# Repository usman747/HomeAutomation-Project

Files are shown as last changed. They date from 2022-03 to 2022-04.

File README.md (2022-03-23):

# SmartHomeAutomation-Project
• Alarm clock was synced with room lights, curtain rails, water heater, water tap & tea kettle using ESP8266 microcontroller
• Implemented IOTs system for connection of above-mentioned nodes & developed App using MIT app inventor, then integrated with Google Firebase 
• Designed PCBs of HMI module and communication boards with sensors / actuators. Some other tasks included; generating list / bill of materials and technical report writing

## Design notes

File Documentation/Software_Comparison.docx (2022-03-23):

# Comparison of Image processing software:

## MATLAB vs PYTHON

MATLAB - Requires proper computer system to execute programs - For real time image processing it runs slower as its code is written in higher level so it had to be converted to lower level first then executed. - Commercial software that comes with standard libraries which have less functions, and extra tool kits cost more - Doesn’t have vast range of datatypes - Difficult to program - Consumes more power because desktop computers are not feasible for low power applications - Consumes large area | PYTHON - Works perfect with mini-computers such as Raspberry Pi - For real time image processing like in our case it runs faster as the program is coded on C++ level. Also OpenCV library is specially designed for image processing. - Open source software with extensive libraries for different functionalities and online support - Powerful datatypes that let organize data easily - Easy to program because it doesn’t require namespaces, so it takes less time to code - Consumes less power - Consumes less area as it as small as a mobile phone

MATLAB provides a costly solution (Desktop PC + Commercial Software) although it does give better results but as a whole that performance is not worth its price.

# Comparison of IOT Platform:

## ARest vs FireBase

Azure & Arest - API and excess methods include JDBC, ODBC and ADO.NET which use windows interface despite the fact that is slow and in-efficient for smart phones etc - Because of windows interface, it is more exposed to viruses and network attacks - Does not update notifications in real time - A bit difficult to implement and connect with large networks. Suitable for systems which does not require real time updates and changes | FireBase - API and excess methods include Andriod, iOS and JavaScript which are mostly used in mobile devices. So it is easier to connect with smart phones - Uses advanced security measures and updates patches accordingly. - Automatically receives updates with new data and update them in real-time - Easy interface for programmer and user, provides fast response because it is better in applications which require real time updates

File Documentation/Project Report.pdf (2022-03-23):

### Introduction And Problem Statement

IOT Based Home Automation provides a solution to control your home appliances from anywhere around the world.

### Tasks:

Alarm clock rings, then
1. Room lights are turned ON
2. Window curtain opens
3. Water heater (Geyser) in bathroom switched ON
4. Water tap opens and tub fills with water
5. Music starts playing when person enters the bathroom
6. After several minutes, water in the jug starts boiling (I-e: Electric kettle is turned ON). If there is no water in the kettle, the system must inform the user.
7. Garage door opens when user tries to enter using 1 layer identification via finger print scanner.

### Concept Design/Proposed Methodology

The first step would be to make an alarm clock using DS1307 clock module with arduino. This alarm module works using I2C Protocol. A 3.2" LCD screen would be used to display the alarm clock and MP3 music player. The LCD Screen will be connected with Arduino. When the alarm clock rings, a relay connected will turn on the room light. aREST dashboard platform will be used in order to automate room lights, electric kettle, water geyser etc. The curtains will roll over using a servo motor controlled through Arduino. The geyser will be turned on using a relay and the water tub will be filled with water by opening the water tap using another servo motor and a water level sensor which will tell whether the tub is filled or not. When tub is filled with water, water level indicator will tell arduino to close the tap. Similarly, the electric kettle will be turned on based on relay switching after a certain time after the alarm rings. The garage door will open after finger-print recognition. The finger print sensor will recognize the thumb/finger print. The user's thumb/finger prints will be stored in admin mode. The finger print will be matched with the print in memory.
The whole project will be carried out in a professional way. The client will get to know progress on each and every stage.

### Objectives/ Goals

The primary objective of this project is to convert your home into smart home. Home automation provides ease of operation and gives you the whole control of your house using a single application which enables you to control your home appliances from anywhere around the world. Any of the house appliances can be controlled over Wi-Fi using Internet Of Things. Automated door-locking facilitates more safety, application can save a lot of precious time. Also, human lives can be saved from short-circuits or electric shocks by elimination of conventional wall switches.

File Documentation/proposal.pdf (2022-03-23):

## Tasks

Alarm clock rings, then

### 1. Room lights are turned ON 2. Window curtain opens 3. Water heater (Geyser) in bathroom switched ON 4. Water tap opens and tub fills with water 5. Music starts playing when person enters the bathroom

6. After several minutes, water in the jug starts boiling (I-e: Electric kettle is turned ON). If there is no water in the kettle, the system must inform the user.
7. Garage door opens when user tries to enter using 1 layer identification via finger print scanner.

## Proposed Methodology

a) Solution for 1. - Relay based switching (6V, 220VAC / 15A) directly from Arduino.
b) Solution for 2. – Two micro switches will be placed on the ends of railings, when the forks of dc motors touch those switches Arduino will cut their power by signaling the motor driver. For closing the curtains 1 micro switch will be placed in the center of the railing.
c) Solution for 3. - Relay based switching (12V, 220VAC / 30A).
d) Solution for 4. – Water tap of the tub will be turned ON after several minutes of previous step (c). For water level detection in the tub we will use sonar sensor, and the tap will be rotated using servo motor (torque 15kg/cm). When the sonar indicates that the tub is full then Arduino will turn OFF the servo motor.
e) Solution for 5. - Music player (MP3 module) with speakers will be turned ON when micro switch applied at the bathroom door changes its states from normally closed to open.
f) Solution for 6. - Relay based switching (6V, 220VAC / 15A) directly from Arduino. Water level indicator sensor (lid inserted inside the kettle) will give the feedback about level of water to the Arduino.
g) Solution for 7. – Finger print scanner module will be interfaced with Arduino and it will identify the ID of the person, if its positive then relay will be switched (12V, 220VAC / 30A).
h) Human Machine Interface will include C# application, 3“touch screen LCD control / information panel and clock circuit made using Digital ICs.
i) Arduino development board will be used for controlling, and NodeMCU for Wifi connectivity of the system with the online firmware such as Cayenne etc.

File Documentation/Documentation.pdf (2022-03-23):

## Contents

Task Division | Error! Bookmark not defined.

## Introduction

The biggest problems to be solved in a city regarding parking space availability are the timely

and accurate real-time information of the drivers, the effective management & monitoring of

parking spaces to increase revenue for the municipality and the cost-effective law enforcement.

Recent studies indicate that the time it takes a driver to find a parking space increases the total

time within the vehicle by 24%. Also, transportation studies indicate that 30% of all traffic in the

average city center is searching for an available parking space.

Fishing for a parking space is a routine activity and it is estimated that nearly 30% of urban

congestion is created by drivers cruising for parking space, according to ITS America’s Market

Analysis. Also resulting in oil wastage, almost one million barrels of world’s oil every day. This

ever-growing traffic congestion and uncertainty in the parking availability and payment have

thus enforced the need for a Smart Parking system. A Smart parking technology that will help

optimize parking space usage, improve the efficiency of the parking operations and help

smoother traffic flow.

Smart Parking solutions are designed to provide drivers an ultimate solution on their journey

from the beginning to end without searching for parking, cost, travel time etc.

In this assignment we have presented a solution for the problems stated above, the solution is

based

Figure 1 on adequate selection of inputs(sensors) and outputs(light, sound, display etc) corresponding to

the main idea of the project while keeping few considerations for example cost, efficiency,

product life span, accuracy etc. In this Smart Parking System, we have two inputs and 3 outputs,

while LCD being a compulsory component of the project which is not being counted as an

output.

## LCD

During the process of designing the project, many sensors were considered and were tested and

all the results were compared in order to select the best components for the project. Since the

microprocessor being used in this project is ARDUINO-UNO, which is a microcontroller board

based on the ATmega328. Arduino is an open-source, prototyping platform and its simplicity

makes it ideal for hobbyists to use as well as professionals. The Arduino Uno has 14 digital

input/output pins (of which 6 can be used as PWM outputs), 6 analog inputs, a 16 MHz crystal

oscillator, a USB connection, a power jack, an ICSP header, and a reset button. It simply gets

connect it to a computer with a USB cable or power it with a AC-to-DC adapter or battery to get

started, and the language used for programming is C-Programming which is the easiest

programming language to operate with.

INPUT#01

INPUT#02

MICROPROCESSOR

ARDUINO-UNO

OUTPUT#01

OUTPUT#02

OUTPUT#03

## Problem Statement

Traffic congestions are something which every individual has come across while travelling by

road, on top of it finding a parking space and going on for chunk of minutes is the very basic part

of a congestion. (Gantelet and Lefauconnier, 2006). In any particular area, street or parking lots

there are plenty of vehicles going around for the purpose of finding a parking, this increases the

fuel consumption, higher energy wastage and more congestion. (Walker, 2014). According to a

study in the U.S the average distance drove to find a parking was a half-mile. Converting that to

year it means 47000 gallons of petrol wasted. (Glatz, 2015). Further basic view is that in general

a big parking lot or any variable sized parking lot gets too complicated to find parking in and it

takes a whole lot of time for them, also usually few drivers are weak in parking and they need

extra help to identify, while parking in reverse or from front, and how to park efficiently. For this

reason a microcontroller has to be made with minimal tools and particulars available such as

Arduino, led, various sensors, etc. The concept being for a parking lot which has specified no of

lots available, the barrier of the parking lot doesn’t open if the lots are full and this will not let

the car go in, and hence they can reverse/take U-turn and go out. At the same time the

programming logic to count the available slots and lift the barrier every time the car is sensed is a

vital part.

As discussed there are few situations in which the parking lots which are very confined of spaces

and might be very difficult to park in. It sometimes becomes very difficult for the drivers to park

in these situations, moreover the rear distance between a wall or any other car parked is invisible.

Hence here accidents or misjudgments are prone to occur. Similar to the earlier concept another

micro controller with sensors and lights has to be designed and implemented which shall read the

distance between the car and the wall or car parked behind so as to alarm the driver for how long

he/she can go on and reverse park or front. This indication can be given using visual or audio.

### Solution

The planned controller offers a lot of ease for user. By implementing it shall allow the viewer’s

to know whether that parking slot has any space or not just by viewing the LCD screen, also the

barrier won’t lift if the space isn’t available. This is to help in directing people to whether a particular parking lot has available parking spaces, which is very important to save wastage of

fuel and time in this rapidly progressing world.

Further the second part in which the Light will show up when the distance is very close for any

car and wall, it is to help the drivers and aid them in parking as it appears many drivers are weak

in parking section and often dents can be seen on the car. This controller action is fit on the wall

or at the road end of the parking lot which shall sense the car coming close and give an alarm

using light to see from the side mirror of the car. Whereas, other means of alarms can be used if

required.

Together the Smart Parking Lot and the Smart Parking shall be referred to as Smart Parking

system.

## Objective

- To make a controller in order to enable cars to enter and exit a parking lot which works

on smart concept.

- To make a controller which is an aid to drivers while parking their car and alarm them

with the distance left.

- To learn how to use a microcontroller
- To learn to implement logic programming
- To learn real time application and usefulness of microcontrollers

## Block Diagrams and System Flow/Implementation

This section explains the general coverage of the input, output and displays connections. This is

a very basic representation which is followed by a flow chart. Since the project is made of two

parts and both the parts are not interrelated there shall be two separate block diagrams and flow

charts. Below the block diagram of the Smart Parking Lot initially, shows how the input

ultrasonic sensors which are placed at entry and exit of the parking lot. These sensors sense the

car and send the waves to the controller which in turn computes the logic and send the command

to the LCD and the outputs connects.

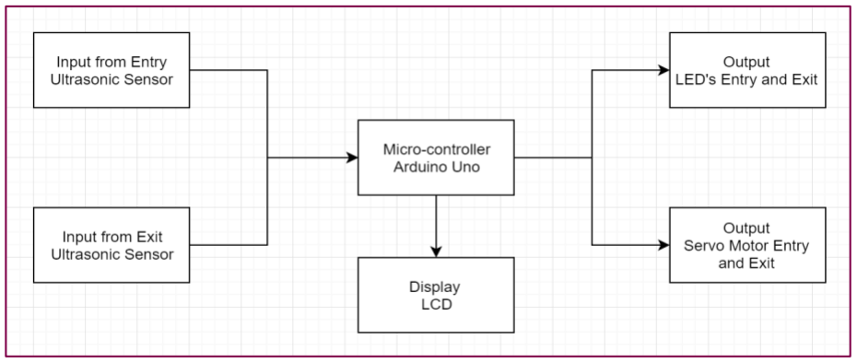
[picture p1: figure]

Figure 2 - Block Diagram of smart parking lot

To understand the diagram better the flow chart will be a perfect tool to explain. Below is the

flow chart of the smart parking lot. Below the flow chart explains the key features of the smart

parking lot, initially when the car is sensed by the ultrasonic sensors at entry or exit point, which

come in the sensor’s range less than 15mm, these sensors then send the command to the logical

unit to check whether the condition 0<x<6 is verified or not. By this it refers to the entry point

when the car is sensed, the number of slots have to checked by the counter whether they are less

than 6 or not, if they are then the barrier opens and car goes in and the CFL bulb light comes on

to denote that the car can go in. Whereas if the slots are 6 already that denotes the parking as full.

This means the car cannot pass in and barrier doesn’t open. After this once the car moves in then

the sensor again senses the distance to be more than 15 and then closes the barrier and switch off

the light.

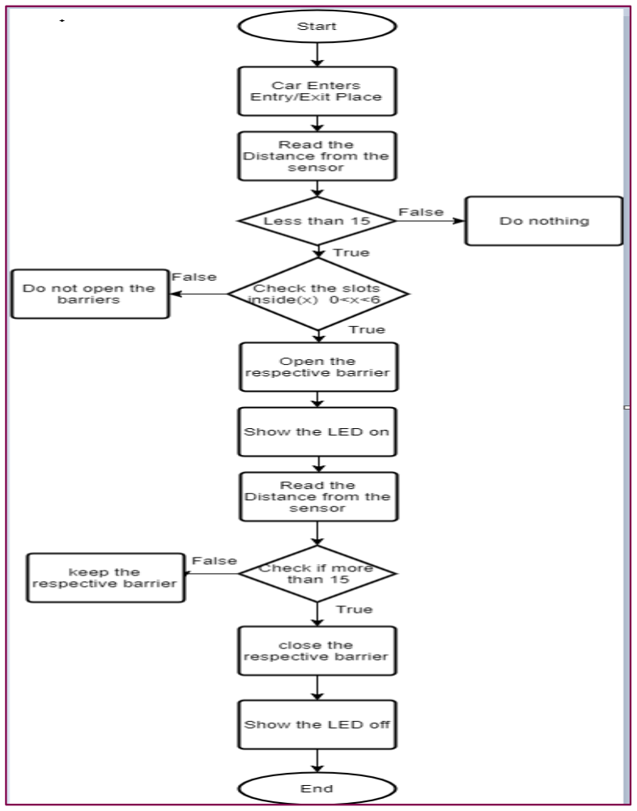
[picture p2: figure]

Figure 3 - Flow chart of Smart parking Lot

Further moving on to the Smart parking which takes in one input from the Photoelectric IR. The

sensor is kept to sense the distance of the car from the car behind or the wall or any other

component where it is fixed. The output of CFL Bulb shows that the car has to stop moving

behind once it’s on.

Figure 4 - Block Diagram of Smart Parking

The flow chart of the smart parking can be described as the car when parking in a slot if sensed

by the sensor which is attached to the wall, then the CFL bulb will light up indicating the driver

that there is no further room. However, once the car is parking within safety distance the bulb

will turn off. Below the Flowchart can be seen in the figure.

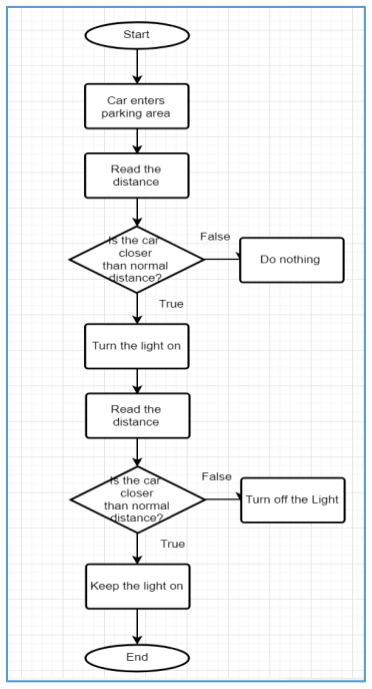
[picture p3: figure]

Figure 5 - Flow chart of smart parking

## Input Interface Design

For this project 2 inputs are being used

### Ultrasonic Sensor(HC-SR04)

Figure 6

HC-SR04 ultrasonic module can offer non-contact distance whose range sensing is up to 2mm

function with the range of 2cm - 400cm. And the range accuracy is up to 2mm.

This module includes ultrasonic transmitter, receiver and control circuit. The Vcc and Gnd pin

supplies power to the sensor for operation and the trigger sensor is used to trigger the sensor to

send sound pulses of high frequency that bounces back of objects. The echo pin is attached to an

pin set as INPUT because it reads the time take for the sound pulse signal to go back and forth

after it is triggered and bounced. (HC-SR04, 2015)

Module Technical Parameters:

1. Working Voltage : 5V(DC)
2. Static current: Less than 2mA.
3. Output signal: Electric frequency signal, high level 5V, low level 0V.
4. Sensor angle: Not more than 15 degrees.
5. Detection distance: 2cm-450cm.
6. High precision: Up to 0.3cm
7. Input trigger signal: 10us TTL impulse
8. Echo signal : output TTL PWL signal

Mode of Connection:

1. VCC
2. Trig(T)
3. Echo(R)
4. GND

Specification:

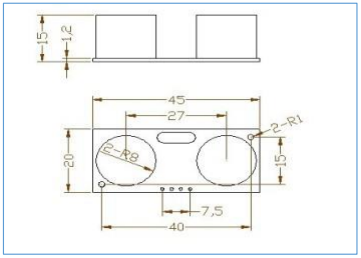
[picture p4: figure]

Figure 7

### Comparison of Ultrasonic Sensor with PIR sensor

Figure 8

PIR sensors detect occupants’ presence by sensing the difference between heat emitted by

moving people and background heat. Ultrasonic sensors detect the presence of people by sending

out ultrasonic sound waves into a space and measuring the speed at which they return. They look

for frequency changes caused by a moving person.

PIR sensors require a direct line of sight between the sensor and occupants in a space. Because of

this requirement, managers can strictly define the sensor’s coverage. Ultrasonic sensors cover the

entire space and do not need a line of sight. As a result, they can detect people behind obstacles.

They also are more sensitive to minor motions, such as hand movements.

COMPARISON

COST | Ultrasonic is cheaper than PIR sensor
COMPLEXITY | PIR sensors are more complicated than the other sensors because there are multiple variables that can affect the sensors input and output.
CALIBRATION TIME | Long calibration time taken by PIR sensor than ultrasonic
SENSITIVITY | PIR sensors are insensitive to very slow motions or the object (i.e. a body) in standing mode while ultrasonic works fine in this condition

Significance of Ultrasonic sensor in the design

After all the comparisons were made between PIR sensor and Ultrasonic sensor, the most

reliable and suitable input sensor was selected which is the ultrasonic sensor(HC-SR04). In our

design, we have two ultrasonic sensors, one is responsible to detect the car at the entrance point

followed by the lifting of the barrier making way for the driver and the second ultrasonic sensor

was placed at the exit point of the parking system and the same process of making way takes

place. Bulk capacitor is also used for decoupling purposes.

Since the barrier is connected to the servo motor which triggers only when the ultrasonic sensor

detects a car it triggers the servo motor and the motor rotates having a delay of 5 seconds which

means the barrier lifts for 5 seconds. And at the same time as soon as the barrier returns to its

original position the count of parking slots decreases implying number of slots remaining which

is being displayed on LCD. In our case we have fixed 6 parking slots so our count starts from 6

slots. Coming to the exit point, the exit sensor will trigger the servo motor again with the same

procedure which being followed the entrance point, but in this scenario the number of slots

increases as the barrier comes back to its original position. Limitations has been programmed for

the number of slots which is 6 and 0, if the number of slots are full and not vacant the barrier for

entrance will not lift up even if the ultrasonic is detecting a car but due to the limitation the car

will not be able to | enter in the parking

lot.

Figure 9

### Testing of Ultrasonic Sensors

Test Results

Figure 10

Referring to the above figure, a serial monitor can be seen having values which are fluctuation

since the testing was being done of ultrasonic. An object was moved in a back and forth manner

in front of ultrasonic, the value 21cm indicates the closeness of the object to ultrasonic and

29.24cm being the farthest distance in between the object and ultrasonic. After this testing was

done then a specific value of 15cm was selected for the application in-order to trigger the servo

motor, for example if the object was 15cm or was closer to the sensor the servo will be triggered

and the barrier will be lifted.

### Photoelectric IR sensor (FC-51)

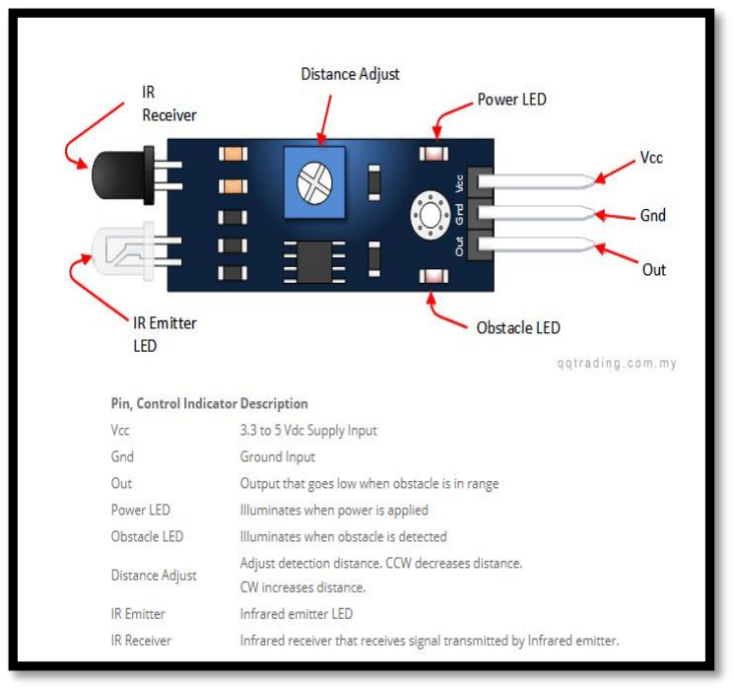
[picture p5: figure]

Figure 11

Module Description:

The sensor module light is adaptable to the environment, it has a pair of infrared transmitting and

receiving tube, tube infrared emit a certain frequency, when detecting direction meet with

obstacles (reflecting surface), reflected infrared receiving tube, after the comparator circuit

processing, green indicator will light up, at the same time signal output interface to output digital

signal (a low level signal), can be through the potentiometer knob adjust the detection distance,

effective distance range 2 ~ 30cm, working voltage is 3.3V to 5V. The sensor detection range

can be through the potentiometer to adjust and have small interference, easy to assemble, easy to

use, etc, can be widely used in robot obstacle avoidance, obstacle avoidance car, line count, and

black and white line tracking and so on many occasions.

Module Parameters:

1. When the module detects obstacles in front of the signal, the green indicator on the circuit

board light level and at the same time the OUT port output low level signal, the detection module from 2 ~ 30cm, 35°detection Angle, test distance can be adjusted through the potentiometer,

adjustable potentiometer clockwise, the detection distance increases; Counter-clockwise tuning

potentiometer, detection distance is reduced.

2. sensors, active infrared reflection detection, therefore the reflectivity and shape of the target is

the key of the detection range. White one black detection range, minimum maximum; Small area

of the object distance, large distance.

3. the sensor module output port OUT can be directly connected to the microcontroller IO port

can, also can drive a 5v relay directly; Connection mode: the VCC - VCC; GND - GND; The

OUT - the IO

4. the comparator USES the LM393, working stability;
5. can be used for 3 to 5v dc power to power supply module. When power on, the red power

indicator light lit;

6. 3 mm screw holes, easy fixed, installation;
7. circuit board size: 3.2CM*1.4CM
8. each module is shipped already compare threshold voltage through the potentiometer to adjust

good, not special circumstances, please do not arbitrarily adjust the potentiometer.

Module Interface Specification:

- VCC voltage is 3.3V to 5V converter (which can be directly connected to 5V single-chip

microcontroller and 3.3V)

- 2. GND external GND
- 3. OUT of small plate digital output interface (0 and 1)

### Significance of Photo electric IR electric sensor

Photoelectric IR sensor was selected over LDR because LDR is highly inaccurate with a

response time of about tens or hundreds of milliseconds. Since this sensor was being used for

parking aid, that is why the sensor has to be accurate with its range and reaction so that this

technology can assist the driver in keeping safety distance from the wall.

As it can be distinguished from figure 1 and figure 2, the difference is the reaction of the output

based on distance. As car comes closer to the wall the danger LED lights up indicating the driver

to stop the car at that moment to avoid the accident.

In figure number 3 serial monitor is displayed having values from the range of 153 to 885. So

500 was kept as the fixed distance which is the safety distance in this project for parking aid.

Figure 14

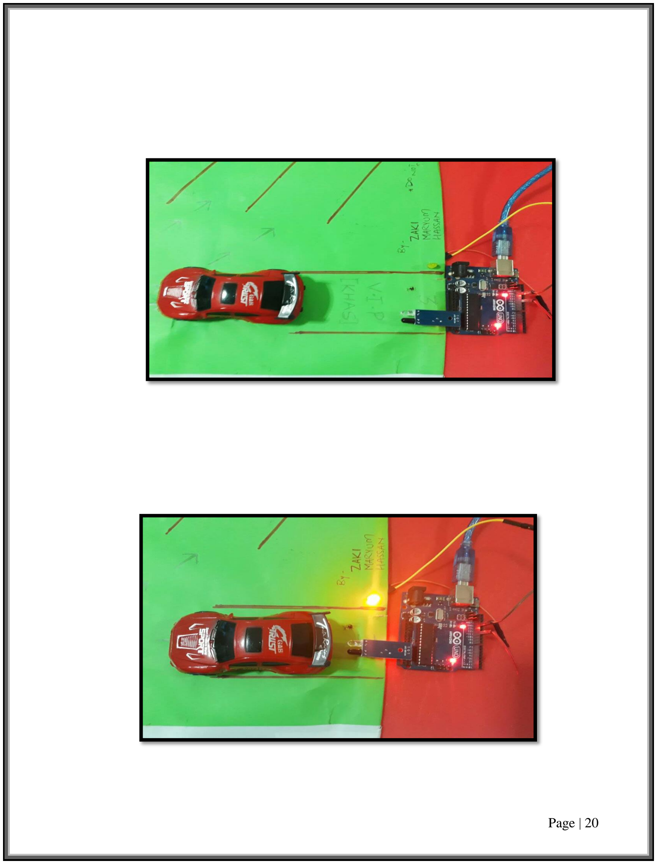
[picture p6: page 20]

## Discussion – Input Interface Design

Designing a smart parking system was a challenging task, few problems were faced among them

one was the selection of inputs for the smart parking system. Comparisons were made between

sensors so that a suitable sensor could be selected. While comparing few considerations were

kept in mind which were the cost of the sensor, durability, accuracy and connecting complexity.

For Input, two ‘Ultrasonic sensors’ and one ‘Photoelectric IR sensor was used. For both the

inputs firstly range was observed and monitored and then fixed range with specific value was

selected according to the application.

Another problem faced was getting incorrect output from the ultrasonic sensor even sometimes

the values were in negative when observed in serial monitor because Sensors can include digital

circuitry which can generate high frequency content, thanks to square waves. You cannot give

these sensors low impedance power paths because of the already long wires; However, you can

limit the high frequency content coming from these sensors to your board. To solve this problem

bulk capacitor was used of 10µF for decoupling. After which the results attained were

satisfactory.

One of the other problem was the unit of distance, the value which was being displayed on the

serial monitor while testing ultrasonic did not have any indication of unit for example cm or mm

so to solve this problem we had to look for a data sheet which had ample information about the

unit and measurement criteria of a particular sensor on which researching we got to know it was

centimeter and then we proceeded with limiting the range of the sensor according to our

application.

Photoelectric IR sensor’s information and connection was very difficult to find because the

information available on internet is very rare to find which resulted in creating difficulties for us

to calibrate with this sensor. Then calibration was done using the technique stated below.

1. Present the sensor with the darkest shape at the smallest distance you need to detect.
2. Turn the pot until the sensor trips.
3. Turn the pot back just slightly until the trip clears.

Since 3 inputs and 3 outputs with a LCD display were connected in the system so the wiring was

an issue as well since all sensors has to be grounded and must be supplied with VCC so it

became quite messy and earlier wires of different colors were used for grounding and source

later on to reduce the confusion all 3 inputs were grounded using the bread board and to

differentiate for each input or output corners of breadboard were used having rails A and B, one

having source other having the ground connection. And then accordingly the wires were

connected corresponding to the placement of sensors.

## Output Interface Design

For any system as it is known consists of and input, output, the process and sometime a

feedback. Input is considered what is fed into the system whereas the output is the result of the

input fed after being processed according to the input data. In literal terms, input is the desired

output. A simple example of a process which contains both output and input is the recording of a

sound and then playing it back, here the voice recorded is the input which is then processed and

reconstructed to play it back.

In a system or a controller which is to be designed there are specific output key terms and points

to be noted. Firstly to know what kind of inputs are needed, then what is the output response of

the system and what is expected, thirdly what process is needed to be done in order to get the

output, fourth and the final one what data has to be kept intact so as to keep the output result in

check. (Study.com, n.d.)

Figure 15 – Block of a systen

There are various ways to represent the output of a system, they can be via text, graphics, audio,

video and so on. Hence the term output design focuses on type of outputs needed, the controls to

manage the output (wiring, connections, drivers, switches), etc. It is highly vital that the output

chosen | satisfy | the | user | requirement | and | serve | the | purpose | of | the | system.

(www.tutorialspoint.com, n.d.)

Basic terminologies which are defined have to relate to the Smart parking systems outputs. The

system uses a microcontroller, arduino uno, which in turn has its own output pins given and most

pins on it are set digital. These pins are to be connected to all the external outputs used and the

pins give out the wave as defined in the program. These output pins can have a high or a low as

set by the program for the required situation, thus to control external outputs these ports must be

connected to it. These external outputs take supply from the control and the signal how to work, in other cases where the larger outputs are connected they need to be supplied externally.

(W9xt.com, n.d.)

With relation to the system designed there were different outputs used. Firstly for the smart

parking lot there was a necessity to show the lots available, this can be done using text output,

secondly after the computations the car which is sensed has to be sent in or rejected thus it had to

be shown using a gate for entry or exit, finally the signal has to be passed to the car to move

forward and go in using a visual light as rules of the road are as such.

Next, for the smart parking lot the distance has to be warned to the driver and similar fashion text

display has to be used, further the alarm has to be put on with visual and audio to assist better.

These determined outputs were put in to consideration and relative devices/materials were

selected. To understand better the following sections will explain the details of each respectively.

### Servo Motor

As discussed earlier the car when sensed by the sensors need to pass in to the parking lot which

are controlled by the barriers, these barriers are controlled by motors on both the sides.

The reason why a servo motor is taken into account is the basic principle of the servo motor to

have a feedback system, which gives the information about the shaft of the motor to the

controller. This prevents any error which might occur while using a stepper motor which takes

the move command only. (Robotiksistem.com, n.d.)

The different types of servo motors are the positional rotation servo, continuous rotation servo,

linear servo. As the name suggests the positional rotation servo goes up to 180 degrees, whereas

the continuous one keeps rotating as set, linear servos are similar to rotation but with more

mechanisms. (Science Buddies, n.d.).

The basic working of a servo motor functionality looks like this:

Figure 16 - Working of servo – Source (Earl, 2015)

Since the Linear servo are difficult to find and very less in number also it is used for larger

applications, the main focus is on the Positional Rotation servo and the Continuous Rotation

servo. (Coker, 2016). The theory behind them and the concept and comparison are as follows.

1. Positional Servo Motors

These are the most widely used motors for accurate and narrow error allowed for positioning. RC

motors can go up to a rotation of 180 degrees, containing a DC motor inside, controller part, a

gear unit, and a position and speed sensing device typically potentiometer. Different types in

terms of sizes are available such as mini, micro, etc. They are mostly low cost and can easily be

configured by microcontrollers for usage accordingly. Application as such used in Robotics

industry, Boats, aircrafts, etc. (Earl, 2015)

Figure 17 - SG90 servo

They come with three wires, one for the voltage supply, one for ground and one for the

command. The advantages of this motor include low cost, wide ranges available in different sizes and shapes with ranges of torques, and controlling ease. On the other hand the drawbacks include

that the rotation is only till 180 degrees.

Specifically RC Micro SG90 in the positional rotation motors, is used with the microcontrollers

for projects demonstrations, while to have a real time application a relatively larger motor with

external supply and relay has to be used. RC Micro SG90 has a duty cycle of 1-2ms, PWM of

20ms (50Hz) and of 5V power and signal. (Datasheet). PWM is the square wave generated by

the microprocessors which is turned on and off within the given limits.

Figure 18 - Pin Diagram

The orange wire which gets the signal is the one which controls the motors shaft, once up to the

maximum position, the motors potentiometer will end the supply and wait for the signal again to

put it down.

2. Continuous Servo Motors

The shaft of this motor can rotate in any direction and with variable speed. Further the shaft can

also rotate for any given duration of time without any stopping. The signal given in to the control

unit takes the information about the speed, duration, direction, etc. They are used in robot driven

industries and fields.

Figure 19 - Continous Servo

Some advantages include being low cost, compact, and again simple to control, drawbacks

include that they can be only used for very small loads, and the position to stop the shaft is not

defined. (Electronics Hub, 2016)

### Comparisons, Selection and Specifications

The comparison of the previously described motors is to see how and where they fit in terms of

using with the microcontroller.

Positional | Continuous
Low Cost – up to RM10 | Low Cost - up to RM10
Rotates 180 degrees or less | Rotates infinitely if set.
Variable sizes | Variable sizes
Adjustable to different loads | Less heavy loads only

From the table above we can see that there is not much difference between the two motors, hence

it is vital to see which one suits best to the microcontroller application of the smart parking

system. The application requires a motor which can lift up when sensed the car and get back to

its rest position after the car is gone. In a typical real time application we can go with the

positional servo since it will limit the barrier to stop at a certain angle and not keep rotating

continuously. Hence the chosen would be the SG90 RC servo motor which can be connected to

the micro controller. The specifications from the datasheet can be seen in the table below.

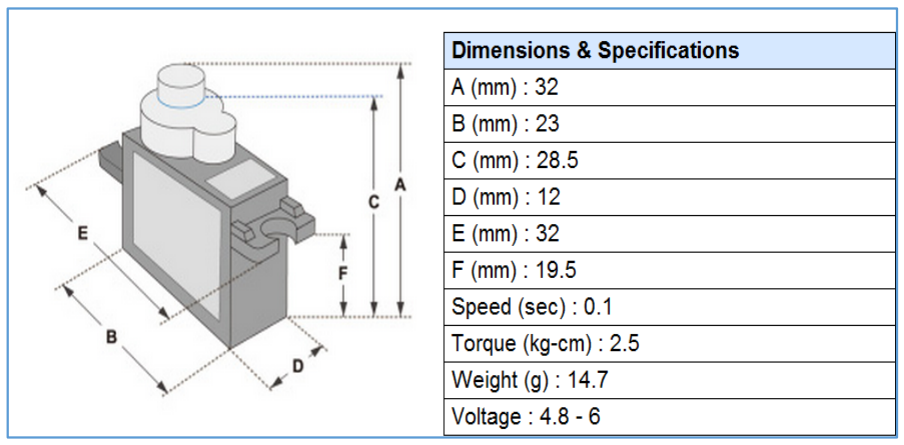
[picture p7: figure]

Figure 20 – Datasheet Specifications – Source Anon, (n.d.). SG90 9g Micro Servo

For the servo motor to be known by its specifications we need to determine its current flow,

current drawn in other words, the voltage required, the resistance, the torque etc. The torque can

be determined by the distance (in cm) and the weight on it. The figure shows the torque to be

20kg-cm, below shown an example:

Figure 21 - Torque Determination

### Testing and Connection of Servo Motor

Testing is the most essential part of output components. Since there are two servos used for the

Smart parking system and both are identical. The circuit is made for both the servos separately to

be checked. The servo motor requires 5V to work, and hence an external battery of 9V is added

and a regulator which controls the voltage is added to supply proper and adequate voltage to both

servo motors. Since there is a bulk capacitor acting as a decoupling capacitor, two capacitors of

0.22uF are used for both the servo motors and two 10uF capacitors are connected to with the

voltage regulator, the system integration part executes and explain further on this. The

connection looks like below:

Figure 22

The pin number 9 from the Arduino goes to the signal controller wire of the servo motor for the

servo present at the entry point of the parking slot. The additional supply of 9V battery is given

to the breadboard. This is then passed through the voltage regulator which cuts the supply to 5V

and hence this 5V is then passed to the servo motors showing as a red wire. The task of a voltage

regulator is to cut the additional voltage and use and pass on as much as it is intended for, here

the voltage regulator is used is LM7805. Which limits the supply to 5V as the servos only need

5V to operate. The capacitors of 10uF are placed near the voltage regulator. A small capacitor of

lower capacitance. 22 uF is connected near the load & that is called local capacitor. The reason

for powering the servo motor externally is because during the servo motor sweep, it draws a lot

of current which exceeds the limit of drawing 10mA from processors and also causes noise in the

circuit. Hence, the supply line for the servo motor is separated from other components.

The code for testing is generated from Arduino examples codes, sweep for servo in which the

servo is given a particular angle and it keeps going till it reaches that angle and then comes back

to the starting position. The delay in the code will generate the PWM sent to servo and hence the

duty cycle and such can be generated. The signal pin of the servo as shown in the previous figure

must be connected to digital pin 9 and thus should be the declaration in the code. Using this code

the servo will turn to 90 degrees and return back to its position with a speed of PWM 20ms. The

speed can be varied for different purpose. The code for testing is shown below:

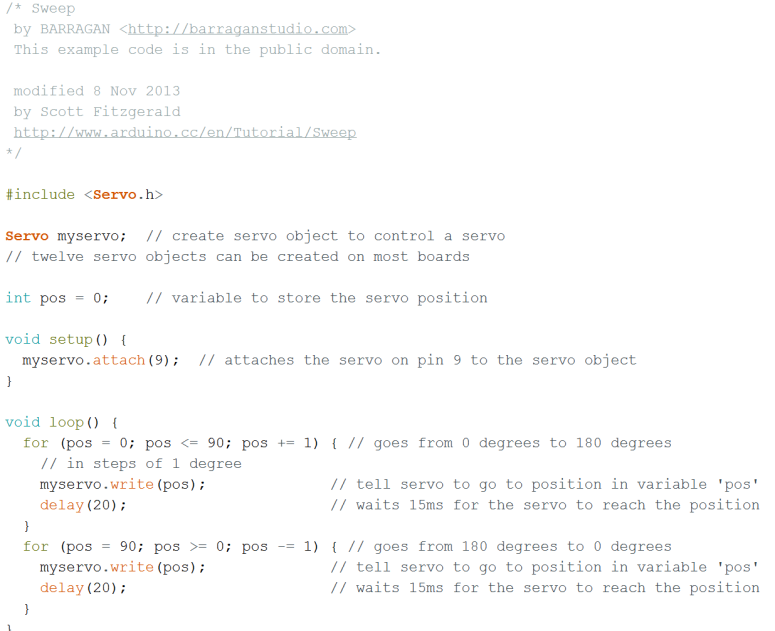
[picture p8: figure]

Figure 23 - code testing

The connection of servo can be shown on the real circuit as below:

Figure 24 - Connections

To measure the current drawn by the servo motor, an open circuit has to be performed. From the

third pin of the voltage regulator has to be pinned elsewhere and then the red probe of the multi-meter should be in series with the Vcc pin of the servo. At different angles the current drawn can

be taken down and noted, namely, the initial start of the motor, the rotation, and the final rest.

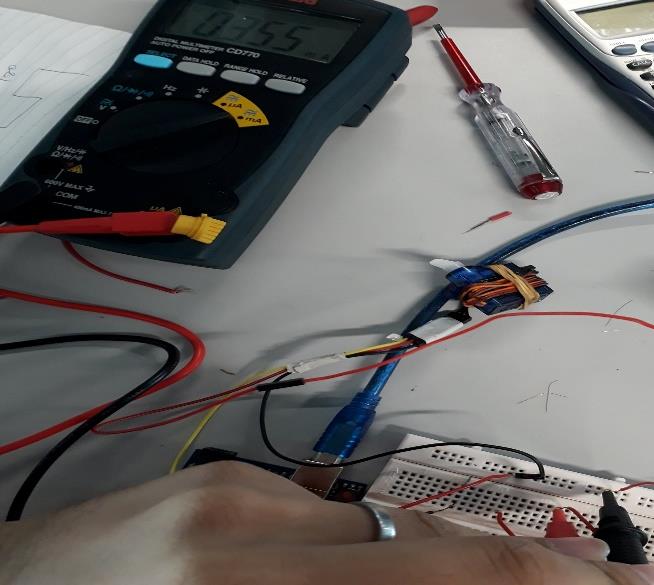
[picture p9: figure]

Figure 25 - Testing

The voltage supplied to the servo motor can also be varied to see the current it draws while the

motor is stationary. This can be done using a potentiometer.

Figure 26

The duty cycle can also generated according to the pulse width given in.

### Code for Servo Motor – For system

Now look at the code which is generated for the servo motor operation in the system. The first is

the library file which is servo.h, this will bring in all the commands that can be used related to

the servo motor.

#include <Servo.h>

Since we have two servo motors we need to define the Servo with a name of choice.

//Defining the servos

Servo servoIn;

Servo servoOut;

Here the pin number 6 is connected to the servo motor present at the exit side.

pinMode(6,OUTPUT);

servoIn.attach(6);

servoIn.write(0);

Next the pin number 7 is connected to the servo motor present at the entry side.

pinMode(7,OUTPUT);

servoOut.attach(7);

servoOut.write(0);

For the Logical part get the distance from the input sensors and specify the slots are greater than

zero, this means it should not go less than zero since the parking lot values can only be a positive

values. The servoIn.write(0) opens the servo gate.

{ if ( | && slots > 0)

{

slots = --slots;

servoIn.write(0); // Open servo gate

….

..... }

The other part of the logical program is to bring back the servo motor back to position.

else if (………)

{ |

servoIn.write(80);

………

}

Similarly for the same entry servo motor the code has to be developed. The only difference is

the maximum slots have to be given is as 6. That means once the count has reached 6 the servo

gate will not open anymore.

if ( | && slots < 6)

The rest of the codes look same like the exit servo which changed name to servoOut.

### LED’s and CFL’s

Since one of the output has to be kept as the visual light, it had to be a light aid or blinking light.

Further due to constraints of a real time application it was necessary to include bulbs, Leds, and

CFL’s to the comparison and conceptual part. Further in this section we can see that how the

selection from these was done.

The tiny Light Emitting diodes are lit up when current passes through them. The internal of an

LED is considered as a P-N junction. The energy given out is from the release of photons which

is the form of a monochromatic light of nanometer of a single wavelength. The basic advantages

include very less power is required, durability is more with good efficiency, and they do not get

warm after use, lower cost etc. (WhatIs.com, n.d.). One of the application of LED’s is that they

are used as indicators in various places.

Figure 27 - LEDS

LEDs come in various sizes and shapes, but a drawback is that they are not ideal for illuminating

large areas. With a range of RM 15 to RM 20, LED’s are more costly than others.

CFL which denotes Compact Fluorescent Light bulbs are a major contributing factor in energy

efficient lighting systems. Easily fit into a normal lamp or bulb sockets. They need to pass

current through them which contain argon and mercury glass, the fluorescent coating gives the

light. A minumim of 11,000 hours are expected from CFLs, and the most convenient. They do

not get dim and are not easily and work good in outdoor temperatures. They come in more

shapes and sizes than any other type. (Anon, n.d.)

Figure 28 - CFL bulb

As a requirement of taking real time application output it was essential to convert this segment of

the output to a real time bulb. Since from the comparison we can see the LED bulb is of higher

price and CFL is at a low cost. Moreover, since its just a prototype the durability was not the

main concern. However we can also see the size of LEDs available were small and have a

limited watt input with less lumens per watt which determines the brightness, the CFL bulb was

bought.

Figure 29 - Comparison

Hence after careful comparison and consideration that the bulb has to be put in open areas where

it will be utilized for parking spaces, CFL bullb is chosen for the application in the Smart parking

system. Further, the specifications of the chosen bulb is given below in the table. (Anon, 2000)

Data | Value
Frequency | 50 Hz
Rate Wattage | 18.0 W
Voltage | 240V
Average Life | 10,000 Hours
Color Temperature | 2700 K
Lumens | 1200

### Relay

There are different types of relays available in the market. Single relays of 5V, 12V, etc and then

other are the relay boards which come with in-built transistor and resistor and an alternative way

to make a circuit of relay. The figure below shows a normal relay and its pin diagram. NO port

is for normally open which means the appliance will be on irrespective to the switch, whereas

NC port is the normally closed port referring to the off point switch.

Figure 30 - Single relay

The second type of relay available is the relay board, which is basic relay mounted on a board

and it is connected with a transistor and diode at the input end. The board is shown in the figure

below and the circuit can be shown as well.

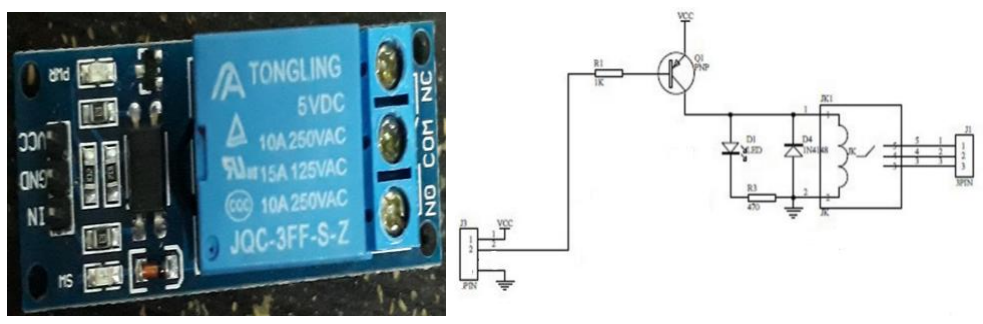
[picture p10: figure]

Figure 31 - Relay board with built transistors

The difference between the two types of relays are merely its circuit and the ability to handle

external current drawn. The need to connect the relay to an external supply and not from the

Arduino is the key reason using the relay board which has a transistor (DP817C) built in. In this

relay board at the input side the ground and the Vcc can be supplied from elsewhere. The Relay

board was used in the Smart parking system and the model was 5V JQC-3FF-S-Z.

Another alternative was to build up a relay, which can be shown in the circuit below

Figure 32

In this case a transistor is added for driving the relay which will take in less amount of current,

by passing little required current to the base. This input pin is the digital pin from the micro

controller and gives pulses, and hence when there is no pulse there is nothing in the coil, and vice

versa. There is not much difference in the built already board relay and a separate process of

making it, both limit the excess current coming in from the input and take in minimum amps to

get started.

The specifications of the relay is shown below:

Data | Value
Coil Power | 360mW
Nominal Voltage | 5Vdc
Maximum Voltage | 6.5Vdc
Coil Resistance | 60Ω
Maximum Switching Current | 10A
Operating Temperature | -40℃ – 85℃
Weight | 10.0g

### Testing and Connection of CFL Bulb

For the regular LED’s when connected the one of the smaller pin was easily connected to the

ground of the breadboard and the other pin was connected to the trigger pin directly.

Since the higher watt (power) of CFL bulb was chosen it was clearly essential that the

connection could no longer be taken from the Arduino or small battery supply. The two bulbs,

one for entry and one for exit had to have an external source supply and hence they were put to

on a bulb holder which was given a wired plug to be inserted to the socket supply. Now the main

key point here is the connection of the bulb to the trigger pin of the controller which shall control

the bulbs status. For this reason two relays of one channel each were taken for both the bulbs.

The task of this relay which takes in the Vcc, ground from the battery which is giving 5V using a

voltage regulator, the trigger pin connection from the microcontroller and on the other hand take

a single wire of the plug and a wire from the bulb holder. This relay works as a switch, by

connecting the bulb to the plug only when the trigger is high. Pins of relay were NC and

common. Below is the connection shown for one single bulb and its testing.

Figure 33 - Testing connection of CFL bulb

The code for testing is given below, the code shows the definition of the digital pin at the

microprocessor, then the pulses sent are high and low for 15000 ms, this will give ideal time for

testing at both the ends.

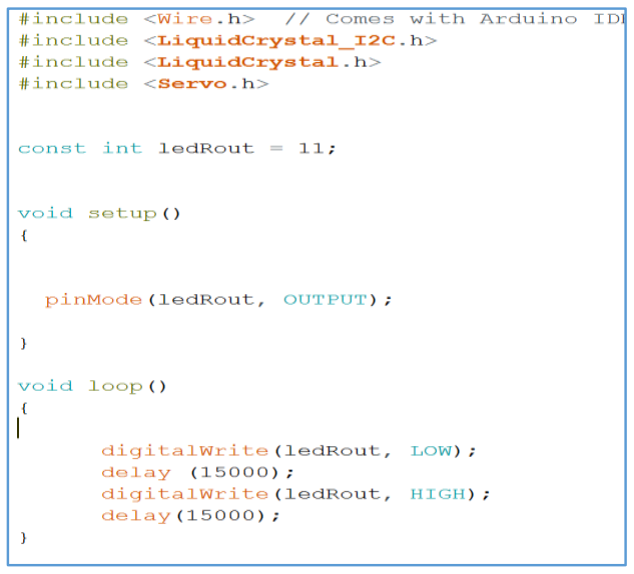
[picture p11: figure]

Figure 34 - code for testing

For better understanding of CFL bulbs a plot of the current prices and the earlier prices can be

done to know better advantages.

Testing the bulb was done by connecting it to the power supply, this power supply was AC

supply directly from the socket which can be checked using the multi-meter. The bulb was

placed on the bulb holder and one line was open circuited to find the current flowing through the

bulb. This gave an idea of the resistance. Similarly other bulbs with varying Watts were

measured and the resistance was found out. The plot of watts vs resistance and watts vs current

gives a fair idea about how CFL bulbs operate and work with how much power. The relay’s

digital pin was first open circuited to find the current it is drawing from the pin so as to know

whether it is exceeding the given limit of 10mA or not. Further for general information about the

relay the Vcc from the voltage regulators output to relay board was open circuited to find out the

current when the bulb was on and also when the bulb was off.

### Code of CFL – For the system

The code for using the Bulb looks as such:

Defining the pins for the two Bulbs, the pins with the wires have to be connected to the relay

from the microcontroller.

const int ledRout = 11;

const int ledGout = 12;

………In the setup |

void setup()

{

…..

}

pinMode(ledRout, OUTPUT);

pinMode(ledGout, OUTPUT);

pinMode(ledRin, OUTPUT);

pinMode(ledGin, OUTPUT);

}

For the logical on and off of the bulb. The digitalWrite gives the signal from the pin to the

destination to whether HIGH (on) or LOW (off) the bulb.

if ( | )

{

digitalWrite(ledGin, HIGH);

digitalWrite(ledRin, LOW);

}

else if ( | )

{

digitalWrite(ledGin, LOW);

digitalWrite(ledRin, HIGH);

}

Since there are two bulbs used for the two points entry and exit, the same fragment can be pasted

for the other bulb as well.

### LCD

For a visible display of text, or count, or any indication we need a display. This display can be

the computer, an external monitor or an LCD. A display is almost the most important part of an

embedded system. Comprising of liquid crystal molecules which control the passage of light and

take the pattern to display is what an LCD is. The Liquid crystal display has its own backlight

which can be controlled using the software. The backlight uses Cold Cathode Fluorescent Lamps

(CCFL). Type 1 LCD which comes with 16x1 display unit, this LCD has 1 line on which 16

characters can be displayed, type 2 is the 16x2 with two rows. The basic model of the LCD used

with Arduino is HD44780, this HD44780 controls the pixels which is present at the back.

The LCD 16x2 comes in two different forms, one with the I2Cbus interface one without it. The

main difference between the LCD with an I2C interface and the non interface is that the I2C

interface one uses only 2 microcontroller pins to set the LCD working and the other 2 pins go to

ground and VCC. Whereas, the non I2C interface one requires all the 16 or less at least 6 pins to

be configured with the controller.

Figure 35 – Pin (Circuitar.com, n.d.)

However the LCD without the I2C interface can be soldered with the Interface by buying

external bus. Almost all the LCD’s take 5V which can directly be supplied from the

microcontroller or external battery or supply. The display of the LCD works by first completely utilizing the row 1 and then going next line, also the cursor can be set using the programming.

(Datsi.fi.upm.es, 2008). The I2C (Inter-IC) by definition is a bi-directional two-wire serial bus

that links the ICs. The SCL pin is the clock pin which is low then only the data with SDL data

pin take place.

Figure 36 - LCD

In this regard referring to the smart parking system it is essential to note that to reduce

complications and wiring mess, the LCD with I2C was used. This saved time and made the

connections easy. The specifications of the LCD can be tabulated below:

Data | Value
Working Voltage | 4.5 – 5.5 V
Supply Current | 0.8 – 1.5mA
Working current | 34mA
Characteristics | 16 Characters x 2 Lines
Module Dimensions | 80.0x36.0x14.0
Operating Temperature | -20℃ - 70℃

### Testing and Connection of LCD

The connection was made purely to display the first initial message when the system is started

and then give the count of the slots available in the parking system. Using the I2C mounted LCD

it has become relatively easy to connect the LCD to the microcontroller.

Figure 37 - Connection LCD

The only 4 connections shown are the VCC and Ground which are taken from and external

battery. The other two pins of the I2C pins are the SDA and SCL pins, the data and the clock pin.

The SDA pin go to A4 and SCL pin goes to the A5 pin of the microcontroller. The code to test

the LCD is given below:

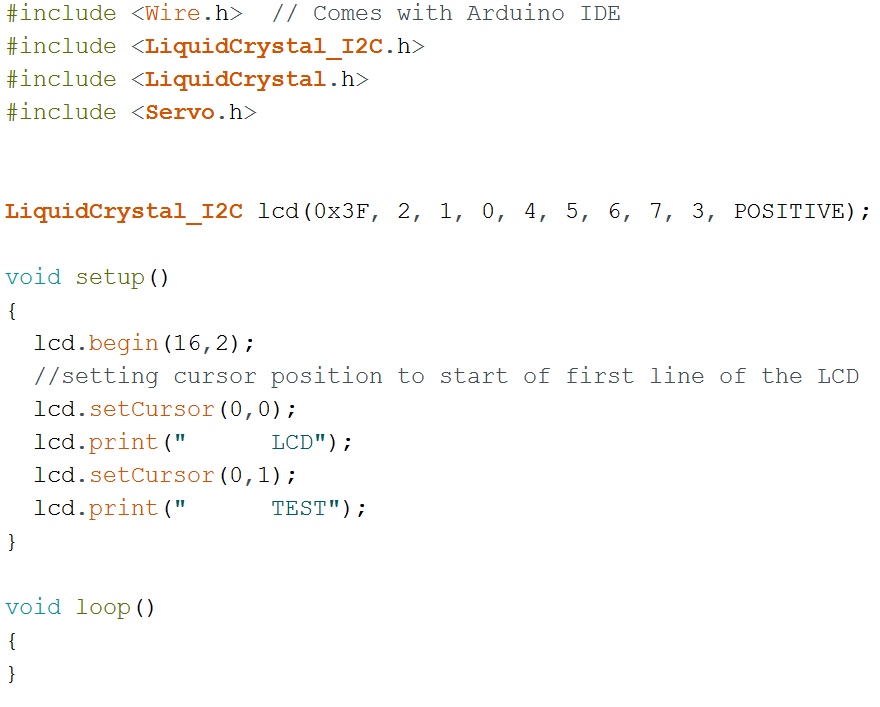
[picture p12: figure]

Figure 38

The code shown in the above figure will print LCD TEST in the two line of the LCD. The

alternative way could be to put it in the void loop section and introduce a delay. The address

specified in the initial lines has to be found out separately as each LCD has different address.

For the testing the I2C mounted on the back of the LCD has a potentiometer which controls the

cursor and its settings. This potentiometer controls the flow of supply current as well. When kept

at ideal condition the potentiometer to view the cursor and the text the current drawn can be seen

by open circuiting the voltage supply to the LCD. Further the resistance can be measured across

the LCD while the voltage is kept constant and supply current can be found.

Figure 39 - I2C

The code when uploaded to the system can show the Text printed.

### Code for LCD – For the system

The code for the LCD can be relatively generated after getting the I2C address as it’s different

for all the different I2C LCD’s. That code and relative finding of the address is given in the

program development section. The code for LCD is generated and can be used as such:

The header files Liquid crystal I2C has to be used to use the library for using I2C mounted LCD.

#include <LiquidCrystal_I2C.h>

#include <LiquidCrystal.h>

//Setting up the LCD with I2C module

LiquidCrystal_I2C lcd(0x3F, 2, 1, 0, 4, 5, 6, 7, 3, POSITIVE); // Set the LCD I2C address

Further we have the initial message display, the word which comes up in the display SMPS

means Smart Parking System. The set cursor command is used to set the cursor from 0, 0 means first column and 1st row. The second one 0, 1 means the 1st column and the next line the 2nd row.

lcd.print command is used to give instruction to the LCD to show the following words.

{

Serial.begin(9600); // Used to type in characters

lcd.begin(16, 2); // initialize the lcd for 16 chars 2 lines, turn on backlight

{

lcd.setCursor (0, 0);

lcd.print("Welcome To");

….

lcd.setCursor (0, 1); // go to start of 2nd line

lcd.print("SMPS");

…

}

This command after displaying initial message leaves the LCD on and its backlight lit.

lcd.backlight();

The clear command is used to clear off anything which has remained on the display. Further as

explained earlier the command to set cursor and print the information after computations and

show how many parking slots are available.

lcd.clear();

lcd.setCursor (0, 0); // go to start of 1st line

lcd.print("No. of Lots: ");

lcd.setCursor (0, 1); // go to start of 2nd line

lcd.print(slots);

}

### Complete Combined Outputs

All the outputs parts and their connections which were defined and described with individual

circuits are now to be brought together after testing. All the connections when made for one bulb

and one servo look like this:

Figure 40 - Combined outputs connection

After connecting all the outputs which is two bulbs, two servos, and for proper usage according

to the smart parking system it is essential to combine them with the input side. And then check

with results of the output while they were working with the inputs.

## Results Discussion on Output Interface Design

According to the connections which were shown in the previous section the outputs were put

together and run with the inputs and also the outputs were checked separately.

The checking of the servo motors for the current drawn at different positions was done. Since the

motor moves continuously it had to be given a huge delay so see the current drawn at specific

angles. The table and the graph can be plotted for current drawn at different positions below.

Position (degrees) | Current Drawn (mA)
0 | 30.78
22.5 | 24.23
45 | 15.44
67.5 | 10.67
90 | 3.56

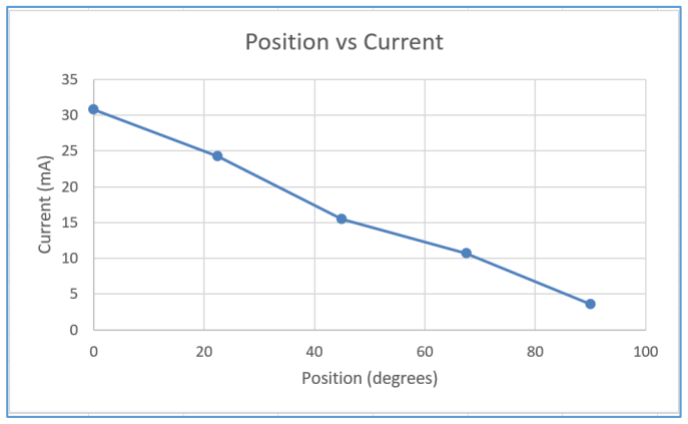
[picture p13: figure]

Figure 41 - Servo Position vs Current

It can be seen effectively that by each degree of closeness to the destination the current drawn

from the servo motor is reduced. This means that the starting point of the servo motor it draws

around 30mA from the circuit which is above the criteria of 10mA and hence external battery has

to be used for using servo motors.

Further the voltage when supplied to the servo motor was up to its requirement it works fine. The

varying voltage when done made the motor to draw more current as it needed to cope up with the

requirements. The voltage and current reading are seen to be:

Voltage (V) | Current Drawn (mA)
5 | 3.56
5.2 | 3.72
5.5 | 3.91
5.8 | 4.12
6 | 4.27

Figure 42 - Servo V vs I

During the testing of servo motors several difficulties were faced, the first and foremost

connecting the servo motor directly to the Arduino and checking. The current drawn was too

high, and the set limit maximum it can draw was 10mA, and hence for this reason external

battery was used. Another issue the battery’s voltage was too high for the servo motor and had

burnt one of it when it was directly connected thus it had to be controlled; it can be done using a

resistance or a voltage regulator, the latter being a good choice due to its exact dissipation of

voltage. Some batteries when used of 6 or 7 volts could generate enough current even though the

battery were controlled to give the servo motor. Hence the higher volts battery had to be used.

The implementation of the CFL bulbs for testing generated results for the bulb which were based

on basic readings at first. While the bulb was in the bulb holder detached from the circuit and

only directly connected to the power supply socket, the voltage across the bulb was read 248V

and the current after open circuit was read 82.1mA.

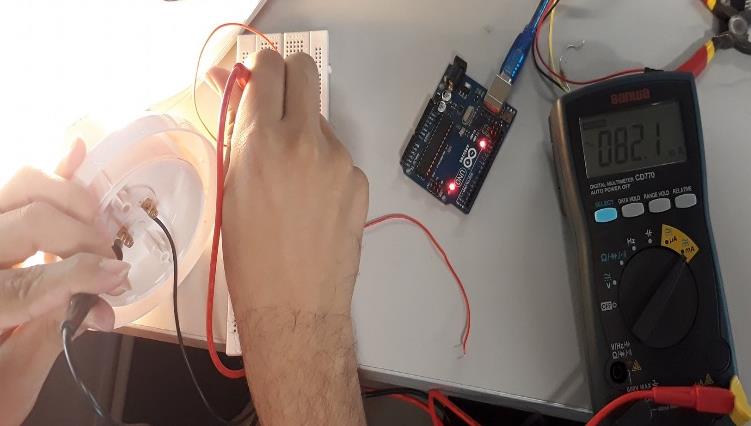
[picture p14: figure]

Figure 43

V = 248 Volts, I = 82.1 mA,

Thus,

P = V*I = 20.3W.

This gives us the idea for the resistance of the bulb which can be given as;

R = V / I = 3.02kΩ.

The tabulated values for different watts of bulbs while taking in 240V to find the resistance and

consumption of current is given below:

Power (W) | Current(mA) | Resistance(kΩ)
6.55 | 27.2 | 8.82
10.03 | 41.79 | 5.7
16.79 | 69.9 | 3.45
19.26 | 77.7 | 3.20
26.67 | 108.33 | 2.215

Figure 44 - a) W vs mA b) W vs k-ohm

From the above result we can infer that, higher the power higher will be the current drawn and

less will be the resistance. The main purpose of higher wattage bulbs is to give more brightness

and hence the current is required to flow for achieving it. The higher the wattage the more was

the supply needed, and it became increasingly difficult to give such a high voltage using battery

and thus AC supply to the bulb had to be used, as that can give enough to light up the bulb. At

first using of incandescent bulb was a choice but they burn and consume lot of power thus we

moved to CFL for real time.

The current drawn by the relay was 3.7mA when the pulse was low given to the board by the

processor as shown in the figure below.

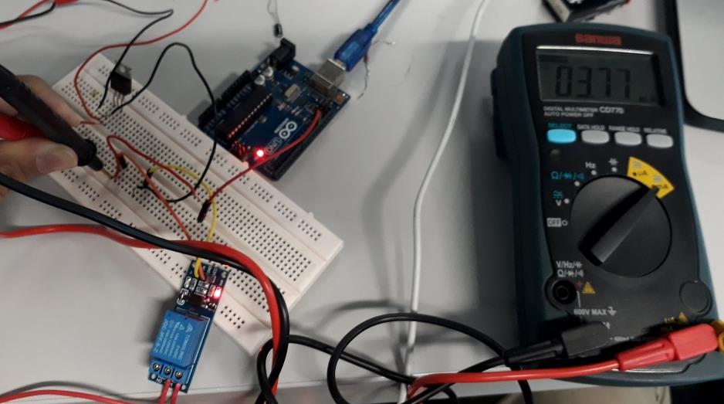
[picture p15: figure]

Figure 45

When the pulse was high it read 77mA, which is similar to when the switch is not connected as

shown earlier. The relay single was used but then it was drawing lot of current, thus the board

relay with a transistor had to be used. Even if this relay was connected to the micro controlled it

was drawing only 4mA but the issue rising was, when the pulse was low to the relay the bulb

was still pulling around 80mA in its off state from the other supply, since it is essential that the

relay while switching doesn’t harm the processor battery to turn on the relay was used again with

a voltage regulator.

As for the LCD testing the given voltage was measure as 4.93V from the regulator taking in

supply from 9V battery. It was then open circuited to find the current as 25.89mA while viewing

the text on the LCD. The resistance at that particular instant can be calculated as 0.19kΩ.

Figure 46

The resistance of the LCD can be varied as explained earlier. Different resistances using the

potentiometer were set and the supply current was calculated by keeping the voltage supply

constant at 5V.

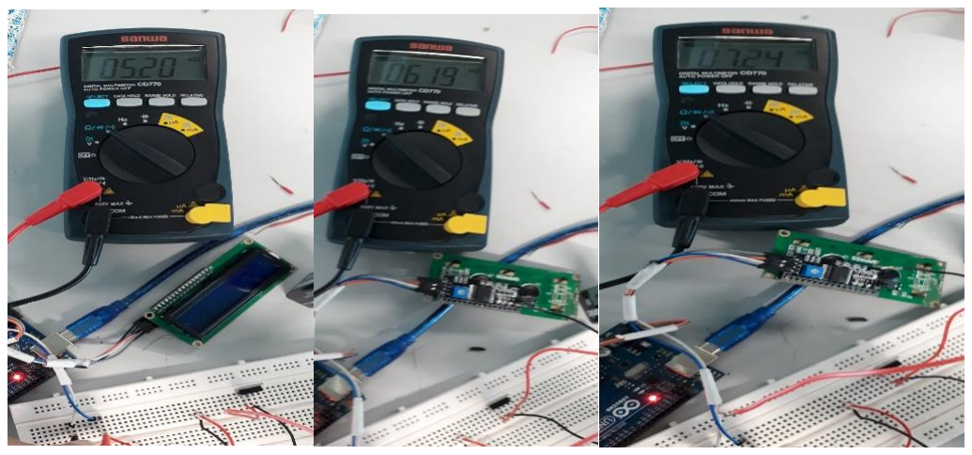
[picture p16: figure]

Figure 47 – Testing Results

Resistance Measured (kΩ) | Supply Current Calculated (mA)
5.20 | 0.96
5.77 | 0.87
6.19 | 0.80
6.73 | 0.74
7.21 | 0.69

Figure 48

From the above graph we can see how the cursor potentiometer behind the LCD in the I2C

module dims the cursor by limiting the current flow. However, the testing of LCD had few

challenges which started with using I2C and the current drawn by the LCD. The code developed for testing gave errors and hence the library was missing which has to be put for using I2C.

Further the LCD drew more than 10mA of current and thus it was essential to connect it to the

external supply. Although the current could be controlled but it then reduced the display of the

LCD, therefore it was best to use battery and then control the voltage accordingly for the LCD.

The overall combinations of the all the outputs when joined with the inputs for the final

prototype of the parking system they did not disappoint and worked effectively. The results of

the output while using with the system can be shown.

The figure below shows how the CFL bulb works in the parking system by being a proper real

time applicable object using the relay board. The connections were made according to how it is

shown in the testing part. The bulb lights up when the car is sensed and the barrier is open for the

car to go in. The pulse is sent to the relay which is acting as a switch and thus the bulb turns off

once the barrier is down and car is gone.

Figure 49 –Working Bulb

The next figure shows how the servo motor is working in the system. It is sent a signal by the

processor to go up and hold till the car is passed, once it passes the servo motor receives the

pulse to go down to normal angle. The angle is fed into the servo motor to move to a particular

height and return in very less time. Limiting the number of slots and the logic is fed into the

servo motor and thus it doesn’t lift up the barrier.

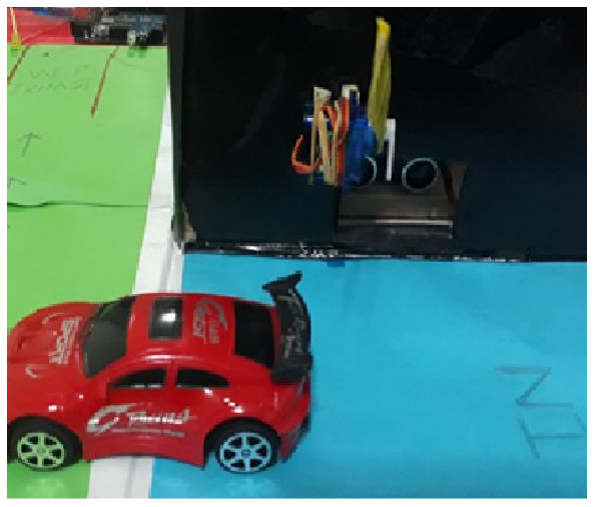
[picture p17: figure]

Figure 50 - Working Servo

The display LCD used in the system using the I2C channel simplified the process and was

effective. As it can be seen in the figure below how the no of lots appear on the LCD screen.

Initially when the system is turned on the LCD screen shows WELCOME TO SMPS, the SMPS

refers to smart parking system. The SDA and SCL pins from the microprocessor transfer the data

to the screen for showing this. Next once the sensors start sensing the slots available and

decrement with every entry. This in-turn shows the counter at the LCD for the drivers to see and

know. The count is given in the code and that is being printed on the LCD.

Figure 51 - Working LCD

Since the completion of the system looks fair extremely relevant to the current situation as

discussed in the problem statement. There were difficulties which came in to the picture while

developing the whole system. The problems were from scratch and effected the output of the

system mainly. For each component of the output the issues and the possibilities were sort while

their own testing time. However there were few which turned up after combining all the outputs

with inputs. This resulted in huge messy connections had to be simplified by taping and so on.

There were three to four different batteries which were used to power up while there were wires

going to the power supply as well from the bulb due to real time relay connection. This can be

reduced by using a single high volts battery but different higher voltage regulator to adequate the

power for each component.

## Program Development

Microcontroller History

During 1970 & 1971 when Intel was working on inventing the world’s first microprocessor,

Gary Boone & Michael Cochran were two engineers of Texas Instruments were working on

quite a similar concept & as a result microcontroller was invented. They built a 4-bit

microcontroller TMS 1000 that had ROM & RAM incorporated in it. From 1972 to 1974, TI

used TMS 1000 in its calculator products. TMS 1000 having different RAM & ROM

configurations were made available for the electronics industries to buy in 1974. Almost 100

million TMS 1000 microcontrollers were sold within 10 years period.

Figure 52: TMS 1000

Early microcontrollers were essentially microprocessors with memory for example, RAM &

ROM incorporated within. There was a time when people used an Abacus just to perform simple

calculations. Bulky wooden frames were utilized just to do some basic arithmetic operations. Vacuum tubes with magnetic drums made an entry as the 1st generation computers but they were

replaced by transistors followed by integrated circuits as an aid for the 3rd generation computers.

The revolution came when microprocessors were created where thousands of Integrated circuits

were built in. A microprocessor lies at the heart of most computers & does all the work within.

Figure 53: Microcontroller

With the passage of time, a lot of advancements were made in the microcontrollers & they were

specified to perform a specific task or to control a specific application for example engine system

in vehicles, mobile phones etc.

Intel Microcontrollers

The most important microcontrollers produced by Intel are the 8048 & the 8051

microcontrollers. In 1976, Intel developed their very first microcontroller 8048 and it was

incorporated in the IBM pc keyboard as a processor. Intel 8048 is actually a member of Intel

MCS-48 family of 8-bit microcontrollers. The MCU has on-chip clock oscillator, 2-8 bit timers,

27 I/O ports, 64 bytes of RAM & I KB of masked ROM. Then IN 1981, Intel developed 8051

microcontroller. It was referred as system on a chip as it had 128 bytes of RAM, 4K byte of on-

chip ROM, couple of timers, a serial port & 4 ports all on single chip. Later when it became

widely popular, Intel allowed other manufacturers to market & make different flavors of 8051

microcontroller. In simple words, it means that if a program is written for one flavour of 8051, it

can run on other flavors as well regardless of the manufacturer.

Figure 54: Intel 8051 microcontroller

Microcontrollers have been used for ages now & their impact is deep. Normally they are

embedded within devices so that action of these devices can be controlled. Typically a

microcontroller is utilized for 3 basic reasons:

1- Receive input using sensors, human intervention etc.,

2- Store the input and process it into a set of actions.

3- Apply the processed data for some other actions that goes as an output.

### Arduino

Arduino is the world’s leading open-source hardware & software ecosystem. This company

offers a range of software tools, hardware platforms & documentation enabling almost anybody

to be creative with technology (Arduino.cc, 2017). Arduino is a single board microcontroller that

is designed to make applications, interactive controls or environments easily adaptive. As far as

hardware is concerned, it consists of a board designed around an 8-bit microcontroller. Arduino

hardware part is basically based on a simple programmable microcontroller board along with the

software part being the IDE (Integrated Development Environment) that is used to write &

upload codes to the physical board. Arduino doesn’t need a separate piece of hardware to load

the code onto the board, a USB cable can simply be utilized unlike other previous programmable

circuit boards. Arduino can create interactive objects by having the capacity to take input from a

variety of sensors & switches & controlling an assortment of motors, lights & other outputs.

Arduino can be connected to the IDE and can be controlled accordingly. Actually the connection

of the wires on the microcontroller board is based on the Arduino programming. Current models

feature things like a USB interface, analog inputs & GPIO pins that allow the user to attach

additional boards. Some of the largest semiconductor companies have jumped into the Arduino

space such as Cypress, STM, Texas Instruments, Freescale, and incumbent Atmel.

There are some major benefits of using Arduino that are as follows:

1- Cheap- Arduino boards are inexpensive when compared to other microcontroller

platforms. The least costly adaption of the Arduino module can be assembled by hand, &

even the pre-assembled Arduino modules cost under $50.

2- Simple- IDE software is easy to use for beginners yet flexible for advanced users.

3- Cross-platform- Arduini IDE software runs on Windows, Mac & Linux operating

operations. As far as other microcontrollers are concerned, most of them are only linked

to Windows.

4- Open source and extensible software - The Arduino software is published as open source

tools, available for extension by experienced programmers.

5- Open source and extensible hardware – Arudino is basically based on Atmel's

ATMEGA8 and ATMEGA168 microcontrollers. In order to help experienced designers so that they can make their own version of the module, plans for the modules are

published under a Creative Commons license. On the other hand inexperienced users can

build the breadboard version of the module to understand the working & in order to save

money (Learn.sparkfun.com, 2017)

ARDUINO C GRAMMAR/LANGUAGE

The aim of Arduino is to provide flexible, easy to utilize hardware & software but the difficulty

lies in the Arduino programming language that controls the hardware & is controlled by a set of

C/C++ functions. Arduino grammar is based on C/C++. C programming language features were

derved from an earlier language called BCPL 9Basic Combined Programming Language). It was

invented for implementing UNIX operating system. In 1978, Dennis Ritchie & Brian Kernighan

invented C programming which was later changed to C++ in early 90s by Bjarne Stoustrup by

introducing concepts that were object oriented. C++ is much more advanced than C

programming. Even C++ and C are sharing lots of its concepts & syntax; still both languages are

different from each other. In order to write a C++ program, one or more source files are required

as it is a compiled language. The source files have to be compiled in order to get a program that

can be executed visa a program called compiler. This process is known as compilation. Compiler

like Keil uVision can be used.

IDE

IDE stands for Integrated Development Environment. It is basically a software application that

provides comprehensive facilities to computer programmers for software development. Typically

an IDE consists of a source code editor, build automation tools & a debugger. Arduino utilizes

IDE in order to open, create & edit programs. The Arduino board with imbedded microcontroller

will behave according to the program written.

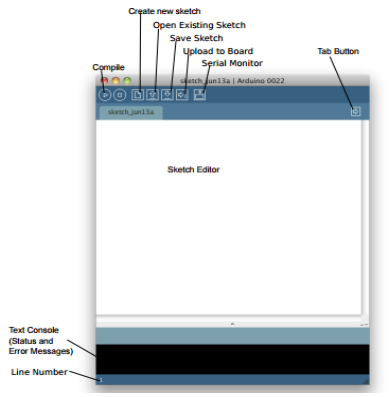
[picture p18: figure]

Figure 55: IDE interface
IDE features:
- Verify – Checks the code for errors compiling it.
- Upload- It basically compiles the code & uploads it to the configured

board by using a USB cable.

- Create new sketch/Program – A new window is opened in order to write a

new program.

- Open Existing program – Basically it presents a menu of all the sketches

in your sketchbook.

- Save – Saves the program
- Stop – Stops the process of compilation.
- Compile- Converts the program into instructions so the board can

understand.

Serial Monitor

- Tab Button – This button allows the user to develop number of files within a program.
- Editor – Where the program is written and can be edited as well.
- Text console – This actually displays what IDE is doing & error messages are also

displayed.

- Line Number – This basically helps in detecting the line number where error has

occurred.

ARDUINO STRUCTURE

Arduino boards are used for making different type of engineering projects & applications.

Arduino board was designed in the Ivrea Interaction Design Institute for students without a

background in programming & electronics. All boards are entirely open-source, allowing users to

build them separately and finally adapt them to their exact needs. Arduino boards are highly

recommended as they are used to build projects, from daily objects to compound scientific

instruments. Arduino boards come in many varieties that can be utilized for different

applications. Certain boards are a bit different from the figure illustrated below but most of the

Arduino boards have these components in common.

Figure 56: Arduino-Uno-R3

As far as the proposed design is concerned Arduino UNO is selected to work with. It is most

basic & commonly used microcontroller. It works in such a way that for a given system the

relation between input & output is required to be defined. One of the major reasons for selecting

is because of its sophistication in managing devices & different components effectively. Arduino

microcontroller is very flexible in terms of analog capability such as reading sensors. It is much

easier to deduce & respond to a variety of sensors with Arduino as it offers beneficial repeated

series of command & respond to sensor.

In order to do coding, the very first thing that is supposed to be done is to study about the

microcontroller that is used for the proposed system. Arduino board is the best board to get

started with electronics & coding. The different components on the Arduino board will be

discuused below just to have a rough idea.

Power USB:

Arduino board is powered by utilizing the USB cable from the computer. The only required thing

is to connect the USB cable with the USB connection.

Power

Arduino boards can also be powered directly from AC main power supply just by connecting it

to the Power.

Voltage Regulator

The basic function of Voltage regulator is to control the voltage that has been provided to the

Arduino microcontroller & stabilize the DC voltages utilized by the processor.

Crystal Oscillator

Arduino calculates time by utilizing the crystal oscillator. The number that has been printed on

top of Arduino crystal 16.000H9H which tells the user that the frequency is in Hertz or MHz.

Arduino Reset

User can reset the Arduino board just by clicking the red button.

Pins (3.3, 5, GND, Vin)

- 3.3 V – It actually supply 3.3 volt (output)
- 5V – It actually supply 5 volt (output)
- Ground- This pin is actually used to ground the circuit.
- Vin – This pin can also be utilized in order to power the Arduino board by using an

external power source.

Analog pins

Arduino board consist of 5 analog pins (A0-A5). These pins actually read the signal from analog

sensor for example temp sensor & then convert it to a digital value so that it can be read by the

microprocessor.

Main microcontroller

Microcontroller is basically a brain of the board. Each and every Arduino board comes with its

own microcontroller. The main integrated circuit is little bit different from board to board. User

must know that what IC his/her board has & the information is given on the top of the IC.

Power LED indicator

When Arduino is powered this LED lights up in order to indicate that board is powered on

correctly.

TX and RX LEDs

Two labels can be found on Arduino board called as TX (transmit) & RX (Receive). They can be

found in 2 places on Arduino board. First, they can be found at the digital pins 0 & 1 in order to

indicate the pins that are responsible for serial communication whereas the Second TX & RX,

TX led lights up with different speed when sending the serial data. RX flashes during the

receiving process.

Digital I/O

Arduini Uno has 14 digital input/output pins and out of which 6 can be utilized as PWM output.

These pins can work as input digital pins in order to read logical values or as digital output pins

in order to drive different modules for example relays, LED’s etc.

### DEVELOPMENT

From information requirements to the final implementation, the system development cycle is an

ongoing process. When the input and output components are connected to the arduino

microcontroller in order to collect data from the environment & control different outputs, a set of

programming logic is developed to interface inputs & outputs as well. Program development

should include all the factors that influence the input & output devices that are connected to the

system. As far as the proposed system is concerned, two separate microcontrollers are used for

both inputs. Inputs with their outputs are tabulated below:

INPUT DEVICES | OUTPUT DEVICES
- Couple of HC-SR04 Ping Sensor | • LEDs • Servo Motors
INPUT DEVICES | OUTPUT DEVICES

Arduino is basically open source computer hardware & a software company. In addition to using

traditional compiler toolchains, the Arduino project provides an integrated development

environment (https://en.wikipedia.org/wiki/Integrated_development_environment) (IDE) based on C++ but in a simplified form.

### Logic

Programming logic is basically a fundamental construct that is applied to the computer science in

a variety of comprehensive ways. Programming logic involves logical operations on hard data

that works according to logical principles & quantifiable results. As far as the programming logic

for the proposed system is concerned, it can be divided into three parts. The very first part

includes data collection from the input devices. Couple of ultrasonic ping sensors are utilized in

order to obtain data from both sides (entrance and exit). In simple words ultrasonic ping sensors

are basically collecting distance information data from vehicles. After receiving the input, the

system is supposed to be programmed in such a manner that it can perform task & can make

decision by using input data. The ultrasonic sensor is utilized in order to sense the presence of

the vehicle and then only barrier will be pulled up so the vehicle can pass. In order to make the

system more precise & accurate the system is programmed in such a manner that if a vehicle

distance is less than 15cm then it is classified as close vehicle & then only barrier will be pulled

up. The microcontroller is programmed in such a manner then when the vehicle is close, arduino

microcontroller will send output signals to turn on the light (bulb) for the entrance side & to pull

up the barrier using servo motors by assigning a certain angle value. When any vehicle comes

close enough to be in the ‘close’ bracket, the no of slots is incremented when the vehicle is

entering & the no of slots is decremented when the vehicle is leaving. The number of slots

actually represents the number of slots that are available in the parking area. LCD monitor is

utilized for displaying the number of slots.

As far as second input is concerned, one photoelectric IR sensor is used in order to obtain data.

IR sensor is basically collecting distance information data from vehicles. IR sensor is used in

order to sense the presence of the vehicle in the parking lot. IR sensor acts as a parking aid in

- Photoelectric IR

Sensor

- LED order to help the driver while parking the vehicle. Once the driver crosses the safety limit and

enters the danger zone, a red colour LED lights up as in indication so that the user can know that

if he continues to do he can bump his/her vehicle & can end up having a dent on his/her vehicle.

The objective is to make a controller which is an aid to weak drivers while parking the vehicle.

### Flow chart

The flow chart illustrated below shows an overview & the actual procedure that the system goes

through in order to perform the specific task in the form of sequence of events that take place in

the background of the main system. In addition it presents the overall structure by using flow

chart. Since flow chart is the most convenient way of presenting the program design. The flow

chart illustrated below shows the working of both sensors that may include Ultrasonic IR sensors

& photoelectric IR sensors. This flow chart is designed to give a better view of the system that

how both inputs work for the parking system.

Initially when car is arriving, ultrasonic ping sensor reads the distance. If the distance of the

vehicle is greater than 15cm, availability of lots is checked. 6 slots are designed in the system. If

any of the slots is empty, barrier will be pulled up making Led ON. If the slots are not available

or parking is full barrier will not open. Ultrasonic keeps on sensing and as soon as the car has

passed, ultrasonic ping sensor will sense the distance and as the vehicle has moved so the

distance is more than 15cm and as a result barrier will close or come back to its original position

making LED light OFF. In case the car has not moved, barrier will stay open until the car has

passed. Now the second input of the system that is photoelectric IR sensor comes into action

while the driver is parking his/her vehicle. Photoelectric IR sensor that is attached with the wall

reads the distance. When the driver is trying to park his/her vehicle & the distance is less than

500 which means that the vehicle is in danger zone and as a result RED Led will switch that is

basically an indication for the driver & when the distance is more than 500 Led light will remain

off. Coming back to the first input when the driver wants to leave the parking lot or wants to exit.

The very same procedure is repeated for exit as well as illustrated in the flow chart given above:

### Pseudocode

The pseudo code for the program development is done in order to achieve the main objectives of

the proposed system is shown below:

ULTRASONIC PING SENSOR

ALGORITHM 1: Connecting Pins and Defining Variables

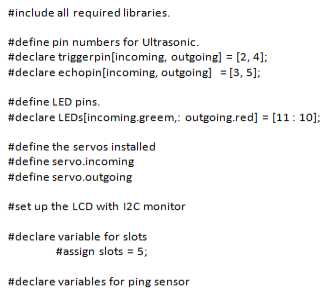
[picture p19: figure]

ALGORITHM 2: Setup Loop

ALGORITHM 3: Main Loop

PHOTOELECTRIC IR SENSOR

### CODE & ALGORITHM EXPLAINATION

ULTRASONIC PING SENSORS

Since the project is made of two parts & both the parts are not interrelated so there shall be two

different codes for both the inputs. Firstly ultrasonic Ping sensor code will be explained followed

by the second input of the system which is Photoelectric IR sensor. A separate block diagram is

designed in order to give a better understanding about the system. The entire code will be based

on this block diagram:

Ultrasonic Ping Sensor Data | Arduino Microcontroller | Servo Motor

Serial Monitor

LEDs

I2C Interface Module | LCD Display INPUT | PROCESS | OUTPUT Figure 57: Block Diagram of the first input

The block diagram shows that the system is divided into three phrases. As far as the very first

phrase is concerned, it collects data from the environment utilizing ultrasonic ping sensors. The

data achieved from the sensor is utilized as input to the Arduino microcontroller. Later arduino

microcontroller is programmed in order to take decision based on the data from the input &

control the actuators. In this case the actuators are controlled output devices. The block diagram

shows that there are four devices connected to the Arduino microcontroller as output. It includes

2 LED’s, couple of servo motors, serial monitor & an LCD connected with I2C interface

Module. The entire explained below is based on this block diagram.

ULTRASONIC PING SENSOR CODE

The very first thing is to add the libraries in the Arduino for the input & output components. A

number of libraries come installed with the IDE but different libraries can be downloaded or

created. In order to utilize an existing library just go to Sketch menu, select ‘import library’ &

choose from the libraries accessible. This will embed a #include proclamation at the top of the

sketch for every header (.h) file in the library’s envelop. Such statements make the public

functions defined by the library accessible/available for user’s sketch. In addition they also signal

the Arduino microcontroller in order to interface that library’s code with user’s sketch once it’s

compiled. As far as the proposed system coding is concerned, libraries available for the I2C

serial Interface Module is utilized for the LCD and the servo motors.

Figure 58: Code Block 1

(Wire.h) library is basically for Arduino connection, (LiquidCrystal_I2C.h) was not available so

it was downloaded from internet and then later added in Arduino library in order to define I2C

module, (Servo.h) is actually a servo library where servo related codes are found.

Figure 59: Code Block 2

As it can be seen in the figure illustrated above that we have created variables that are

representing different pin numbers for input & output devices. Pin numbers are being stored in different variables for defining the pins are constant integers. Using the predefined pin number

values from the code, hardware has been built & implemented accordingly. Hence hardware is

using the same connected pin number values. In figure above, trigger Pin for incoming &

Outgoing are added in order to inform the microcontroller Arduino that Trigger Pins are

connected to pins defined above. In the same manner echo Pin & LED’s are also added.

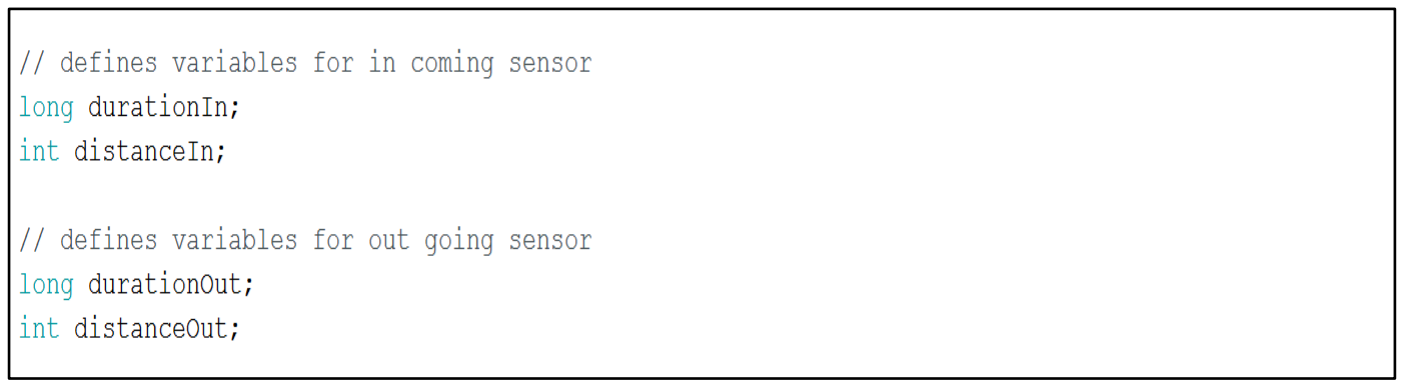
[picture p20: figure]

Figure 60: Code Block 3

It can be seen in the illustrated figure that the variables for the duration & distance for both

ultrasonic ping sensors are defined. Basically these variables are utilized in order to store the

time it takes for the sound wave to bounce & come back of an object. In others words, these

variables are utilized to store the distance of the vehicle.

Figure 61: Code Block 4

In figure above two servos are defined as (servoIn) & (servoOut). (servoIn) is for entrance gate

& (servoOut) is for exit gate. The third line of the code in the above figure represents the setup of

LCD utilizing I2C interface module. The LCD’s address is supposed to be found by utilizing a

port scanner and that’s how it was done. The address was found to be placed in 0x3F address.

LCD address is basically the address on which it communicates with LCD. As far as other

numbers are concerned, they represent different pins of the LCD. At the end of third line the term POSITIVE is utilized in order to turn the backlight on for the LCD. If POSITIVE is

replaced by NEGATIVE then the LCD will work but the backlight will not turn on.

Later no of slots are identified that actually represent the no of slots available for vehicles in the

parking system. The number of slots is assumed to be 6 as the prototype designed had a parking

space for 6 vehicles only.‘incrementIN’ & ‘incrementOUT’ are defined for the incrementing &

decrementing purpose. They are defined as ‘1’ so it only increment or decrement once for each

vehicle passing.

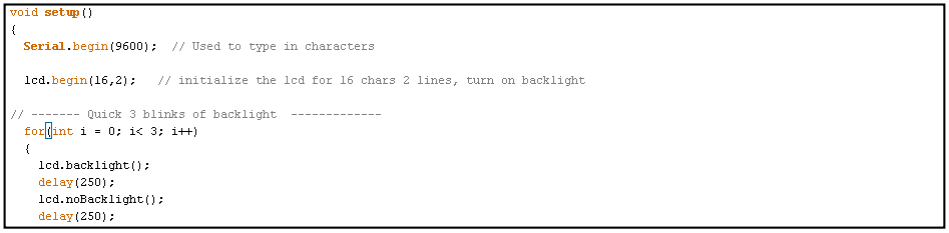
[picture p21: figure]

Figure 62: Code Block 5

Void setup () carry the set of code that is executed when the Arduino microcontroller is supplied

with power. In addition it should be kept in mind that this code is only executed once. Moving

forward to the first line of the code where baud rate is assigned as 9600. This is done so that the

computer can communicate with Arduino Microcontroller by utilizing USB cable. The baud rate

which is 9600 actually makes sure that the data from Arduino can be seen in the serial monitor

(output). In the very next line lcd.begin is utilized in order to turn on the LCD display by using

I2C interface module. In the very next line for loop is used where an auxiliary index variable is

defined called ‘i’ that is denoted in for loop & is either incremented or decremented at the end of

the loop. The index variable is assigned with the value of zero. As far as the value is

between 0 &3, the loop will repeat. At the end of the condition, the ‘i’ value is incremented that

simply means that this set of code that is written within for statement can be executed for 3 times

only. Lcd.backlight() and lcd.nobacklight() are utilized to turn on and to turn off the backlight for

LCD followed with the command of delay(250) that is basically used to suspend execution of a

program for a particular time in milliseconds. In addition this makes sure that LCD’s backlight is

turned ON for 0.25 seconds & then turned off for the same duration of time. The entire process

will be repaired thrice.

Figure 63: Code Block 6

LCD that has been used is 16x2 that means that it consist of 16 columns & 2 rows. Lcd.setCursor

is utilized to set the starting point of the text to be displayed on LCD screen following by the

proposed topic information in the form of a string while completing the same information at the

second row.

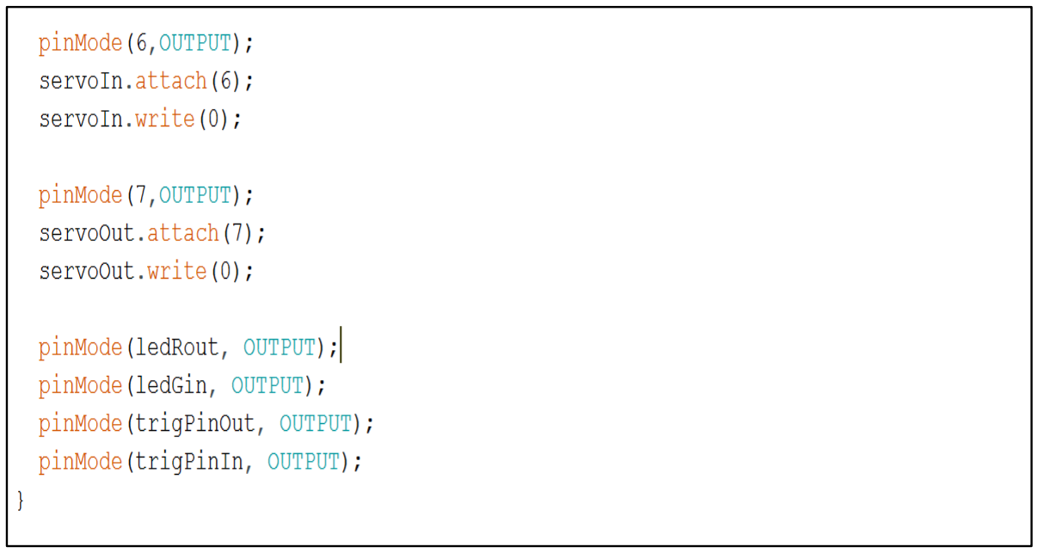
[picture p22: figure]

Figure 64: Code Block 7

This is rest part of void setup() code. It can be observed by looking at the code that servoIn that

is basically for the vehicles coming inside to park the vehicle is connected to pin no 6 whereas

the other servo motor servoOut that is basically for the vehicles leaving the parking is connected

to pin no 7. servoIn.write and servoOut.write is utilized in order to set their angles to zero degree

which is done so that the servo motors initially remain in their normal position. In the last four

lines, LED’s & trigger pins are set to OUTPUT for ultrasonic ping sensors that basically helps

the processor to send output signals by utilizing these pins.

Figure 65: Code Block 8

Void loop () is the main loop of the program in Arduino interface. In other words, the loop

function is the main body of a loop that is running in a master program. The code written under

void loop () represents the working of ultrasonic ping sensors (input) & is repeated until the

setup loop is executed completely. ‘digitalWrite’ command is utilized to assign the value of the

trigger pin (input) to LOW that basically clears the trigger pin & make sure that it is not sending

any sound waves. Then a delay of 2 microseconds is added by utilizing ‘delayMicroseconds’. A

delay of 2 microseconds is given so that the trigger pin can completely clear. ‘digitalWrite’

command is utilized again to assign the value of the trigger pin as HIGH for 10 microseconds.

This means that during this time the trigger of the ultrasonic pin sensor is sending sound waves

that are reflected back to the echo sensor after it bounces an object. After that, it is again turned

off & the echo pin is set as HIGH that simply means that it is turned ON so that the sensor can

calculate the time taken for the sound to wave go back & forth. distanceIn is the variable utilized

to store the distance of the vehicle that is incoming which is done by utilizing mathematical

equation to get the distance in centimetres as we know that speed of sound in air. Mathematical

equation is given as follows:

S=vt

It addition it should be kept in mind that at the end of each sensor, the process of calculating the

distance , a delay of 50 microseconds is kept in order to make sure that both the ultrasonic ping

sensors doesn’t know interface with each other during operation. The process explained above is

for incoming sensor & now the very same process will be repeated for the outgoing sensor.

Figure 66: Code Block 9

It can be seen in the figure above that Serial.print is used. Serial.print is used to display the

distance of the incoming & outgoing vehicles on the serial monitor. Serial monitor is also an

output that basically displays the distance data collected from the sensor along with the no of

slots that are available on the LCD screen as LCD screen is not enough and it will not be able to

display both data. Starting with the first line of the code ‘distnaceIn: ‘. It should be noted that

there is a space in the straing value in order to add the variable distanceIn next to it. Command is

given to print the ‘distanceIn: ’on the serial monitor. The very same process is then repeated for

the distance for the outgoing vehicles.

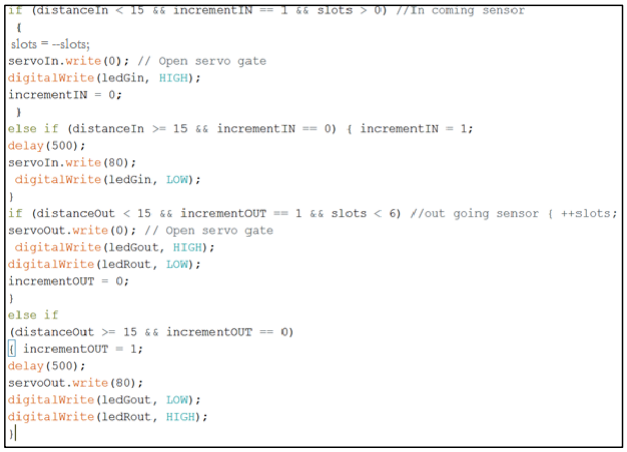
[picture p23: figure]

Figure 67: Code Block 10

The code written in the above illustrated figure is the most important code of the development

process. If-else statement is utilized in order to make conditions so that the system’s output work

based on the input. If-else statement is using conditions which is that if the distance of the

vehicle is less than 15cm then only slots will be decremented by utilizing ‘- - slots’ .In addition

‘slots >0’ condition is given which means that if the number parking slots available are more

than ‘0’ then on this a signal will be sent to the servo motor and the barrier will be pulled up so

that the vehicle can pass. At the very same time the green LED is turned ON that basically gives

an indication that the vehicle can pass and as soon as the vehicle has passed barrier comes back

to its original position making the LED light off. Green LED is turned on as ‘HIGH’ command is given indicating that the vehicle is now allowed to pass. It is to be noted that there is a second

condition in the if statement; the incrementIN must be 1. It can be seen in the above figure that

the incrementIN was initially set as 1 while declaring the variables which means that when the

very first vehicle arrives all the conditions of if-else statement are satisfied & the code is

executed. At the end, incrementIN is set as zero which is done in order to make sure that the no

of slots to be decremented only once when the vehicle is in range.

Another if-else statement is utilized for the distance greater than 15cm. Once gain incrementIn

variable is set as 1 which actually makes sure that once the vehicle moves on, first if statement

conditions are met when another vehicle comes nearby. Moreover a delay has been kept in order

to make sure that the driver has some time to pass through before the barrier comes back to its

original position & then at the end servo motor comes to its normal ‘closed’ position. Green LED

is turned off as ‘LOW’ command is given.

The very same logic is utilized for exit gate. When the sensor senses the vehicle that is within the

range (15cm) this means first condition is satisfied. Another condition is applied by using

‘slots<6’ which means that if the no of slots available in the parking lot is less than 6 then only

servo will move 80º pulling the barrier or opening the gate and Green LED will turn on and as

soon as the vehicle has passed barrier will come back to its original position making LED off.

The condition of 0 and 6 applied for entrance and exit in order to make the system work in a way

then only if the of empty slots are available then only vehicle can go inside in order to park

his/her vehicle. Then an ‘else statement’ is used which shows if the sensor gets the distance more

than 15cm then the servo motor doesn’t move so as a result no increment is shown.

Figure 68: Code Block 11

This is the last block of code that is basically related to the displaying the no of slots in the

parking space on LCD screen. Firstly, LCD is cleared from inputs that were displayed previously during the setup loop and then the cursor is set to the 1st row & 1st column. As we know that the

LCD has 2 rows so the very first row is assigned to display the ‘No of lots’ whereas the 2nd row is assigned to display the value of the variable called ‘slots’. This variable is storing the no of

slots available so the very same value is displayed on LCD screen so the driver can see.

Note: The entire program has been attached in the Appendix for reference.

### PHOTOELECTRIC IR SENSOR FOR PARKING AID

Further moving to smart parking system that takes its other input from the Photoelectric IR

sensor. This sensor is kept in order to sense the distance of the vehicle. The main idea is that 6

different Photoelectric IR sensors are placed for each parking lot. These sensors are actually

fixed with the wall so that when the driver is parking his/her vehicle, distance can be measured

and once the vehicle is in danger zone, the output of CFL bulb switches ON in order to alert the

driver so that the driver can stop. The CFL bulb stays OFF until the vehicle is in safe zone.

Figure 69: Block diagram for the 2nd input

The block diagram illustrated above shows the simple connection of Photoelectric IR sensor. In

order to make the system run a block of code has to be written. The code to make the

photoelectric IR sensor work is explained below:

PHOTOELECTRIC IR SENSOR CODE

Arduino libraries are basically the files written in C or C++ that provide your sketches with extra

functionality for example the capability to control an LED matrix.

Figure 70: Code Block 11

The Arduino environment is extended with the utilization of libraries. They provide extra

functionality for use specially working with hardware or manipulating data. As it can be seen in

the figure illustrated above that (Wire.h) library is used for Arduino connection.

Figure 71: Code Block 12

Void setup () function is called when the code is executed when the Arduino microcontroller is

supplied with power. It is used to initialize variables, pin modes, start utilizing libraries, etc.

Void setup () will run only one after every time Arduino board restarts. As it can be seen in the

figure illustrated above that A1(ground pin) and A2 (Vcc Pin) are set to OUTPUT whereas A0 is

set to INPUT so A0 will be used to read what photoelectric IR sensor is saying. Pin 11 is

basically connected to LED which is basically the output that will be used as in indication to

alert driver once the driver enters the danger zone. Then the photoelectric IR sensor is turned ON

by using digitalWrite and making ‘A2’ HIGH which means 5V is supplied to the terminal of

sensor by Arduino microcontroller whereas A1 is LOW which means that sensor ground is

connected with Arduino ground. . Moving forward to the first line of the code where baud rate is

assigned as 9600. This is done so that the computer can communicate with Arduino

Microcontroller by utilizing USB cable. The baud rate which is 9600 actually makes sure that the

data from Arduino can be seen in the serial monitor.

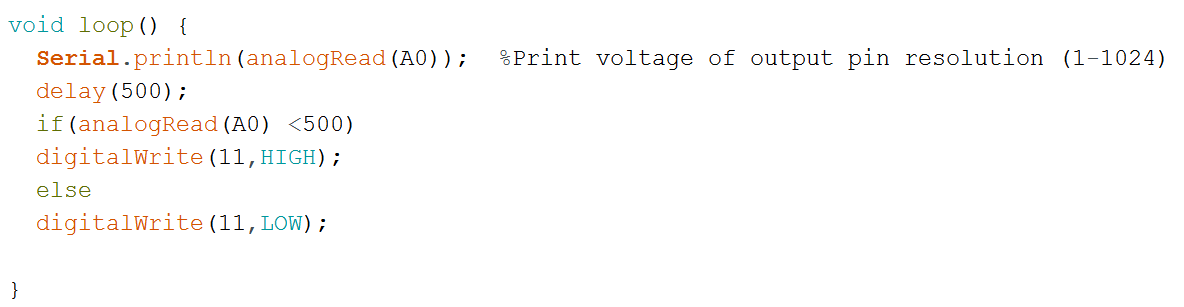
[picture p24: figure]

Figure 72: Code Block 13

Void loop () is the main loop of the program in Arduino interface. In other words, the loop

function is the main body of a loop that is running in a master program. The code written under

void loop () represents the working of Photoelectric IR sensors (input) & is repeated until the setup loop is executed completely. The loop function is repeated continuously as it is called by a

hidden loop that actually controls the execution of the Arduino Program. ‘Serial.printIn’ means

print the data to the serial port. Data is basically the information achieved by the photoelectric

sensor. So this will be printing the voltage of output pin resolution (1-1024). Then a delay of

0.50 microseconds is given by utilizing ‘delay’. If-else statement is utilized in order to make

conditions so that the system’s output (LED) work based on the input. The code written within

if-else statement is the most important code of the development code. If-else statement is

utilizing conditions which is that if the reading achieved from input (IR sensor) is less than 500

as the reading can be anything from 1-1024, pin 11 is made HIGH which means that LED will

turn ON followed by else statement that means that if the distance is greater than 500 then LED

will remain OFF. If-else stament is used for the implementation of parking aid. The entire code

can be summed up by saying that 500 is kept as safety point. When the distance of the vehicle is

less than 500 from the wall then the red LED will switch ON indicting that the driver needs to

stop as he/she can end up hitting his/her vehicle & when the distance of the vehicle is more than

500 from the wall, LED will remain OFF.

Note: The entire program has been attached in the Appendix for reference
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

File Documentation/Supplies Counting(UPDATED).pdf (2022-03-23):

### Introduction And Problem Statement

Count the number of supplies in the kitchen cabinet.

### Concept Design/Proposed Methodology

Counting of the supplies boxes in the cabinet will be performed by tracking Multiple Objects Using OpenCV. The raspberry pi is known for its excellent results in usage for image processing. The supplies jars will be marked using Red, Green, Blue tapes or sheets which will be recognized by camera and using OpenCV image processing technique/library, jars will be counted based on colour detection.

For this purpose, following equipment will be necessary.

### Project Budget

Component | Quantity | Price (PKR)
1) Raspberry Pi 2 Model B+ | 1 | 5500
2) Camera Module 5MP | 1 | 2500
3) Memory Card | 1 | 500
4) Adapter 5V | 1 | 500
5) Adjustable camera holder mount | 1 | 400
Total | | 9400

### Objectives/ Goals

The main objective is to keep an eye on the available supplies and to get notified when any supply runs out. This way, user will keep updated and shortage of any supply can be prevented.

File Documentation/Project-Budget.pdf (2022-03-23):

Project Budget:

Component | Quantity | Price(PKR)
1) Arduino MEGA 2560 | 2 | 2500
2) NodeMCU (ESP32) | 1 | 1000
3) Relay (12V) | 2 | 200
4) Relay (5V) | 2 | 250
5) Micro Switches | 6 | 300
6) Servo Motor | 1 | 1000
7) Water Level Sensor | 1 | 100
8) Ultrasonic Sensor Sonar | 1 | 250
9) MP3 Module | 1 | 400
10) Memory Card | 1 | 500
11) Speaker 8ohm | 1 | 50
12) LCD 3.2" | 1 | 4000
13) Finger Print Scanner | 1 | 5000
14) Clock Module | 1 | 200
15) Buzzer | 2 | 100
16) PCB Board | 1 | 700
17) Bread Board | 3 | 600
18) Curtain Motor Channel | 1 | 2500
19) DC Motors | 2 | 1000
20) Motor Driver Module | 1 | 400
21) DC Adapter 5V | 2 | 1000
22) DC Adapter 12V | 1 | 600
Total | | 22650
* Please note that there can be 10% tolerance in overall price of the items depending upon their availability or a better component selection.

Total Expense:

Cost Of Components = PKR 22650/-

Project Development Cost = PKR 25000/-

Total Cost = PKR 47650/-

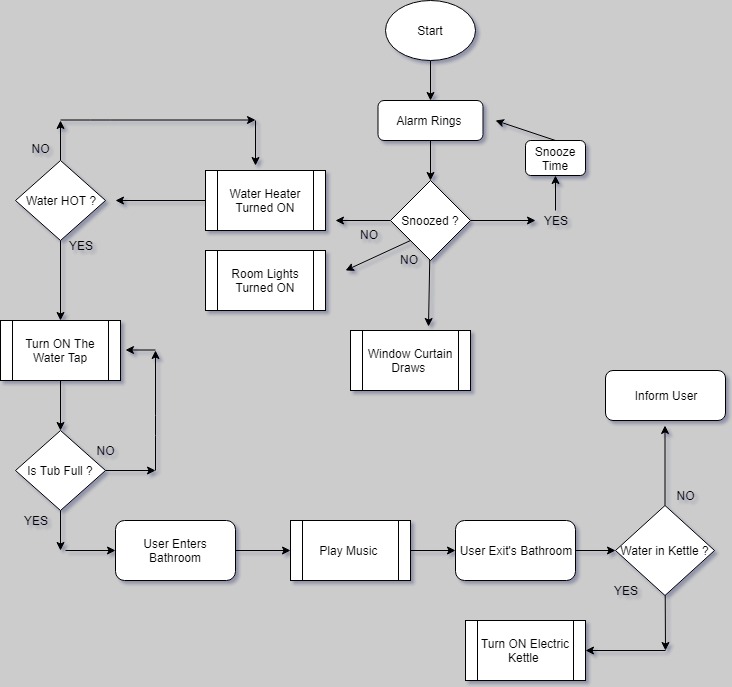
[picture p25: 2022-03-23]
Documentation/Untitled Diagram.jpg

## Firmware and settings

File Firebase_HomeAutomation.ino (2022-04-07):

// The Code is modified and written by Alok Shaw, the creator of the Youtube channel : www.youtube.com/roboshala and runs an educational blog : www.roboshala.com
// Code modified by Usman for prototype of smarthomeautomationproject

#include <ESP8266WiFi.h>
#include<FirebaseArduino.h>
#define FIREBASE_HOST "myhomeauto-cd617.firebaseio.com"                     //Your Firebase Project URL goes here without "http:" , "\" and "/"
#define FIREBASE_AUTH "C8CJWvomB9BrpdKIX0hDID2vHG4G8dAeEmzocnDg"       //Your Firebase Database Secret goes here
#define WIFI_SSID "NAK-PTCL-B"                                               //your WiFi SSID for which yout NodeMCU connects
#define WIFI_PASSWORD "xylophone"                                      //Password of your wifi network 

#define Relay1 12 //D6
int val1;

#define Relay2 14 //D2
int val2;

#define Relay3 4  //D1
int val3;

#define Relay4 5 //D5
int val4;

void setup() 
{
  Serial.begin(115200);                                                   // Select the same baud rate if you want to see the datas on Serial Monitor
  pinMode(Relay1,OUTPUT);
  pinMode(Relay2,OUTPUT);
  pinMode(Relay3,OUTPUT);
  pinMode(Relay4,OUTPUT);

  digitalWrite(Relay1,LOW);
  digitalWrite(Relay2,LOW);
  digitalWrite(Relay3,LOW);
  digitalWrite(Relay4,LOW);



  
  WiFi.begin(WIFI_SSID,WIFI_PASSWORD);
  Serial.println("connecting");
  while (WiFi.status()!=WL_CONNECTED){
    Serial.print(".");
    delay(200);
  }
  Serial.println();
  Serial.print("connected:");
  Serial.println(WiFi.localIP());

  Firebase.begin(FIREBASE_HOST,FIREBASE_AUTH);
  Firebase.setInt("S1",0);                     //Here the varialbe"S1","S2","S3" and "S4" needs to be the one which is used in our Firebase and MIT App Inventor
  Firebase.setInt("S2",0); 
  Firebase.setInt("S3",0); 
  Firebase.setInt("S4",0); 
  
}
void firebasereconnect()
{ 
  Serial.println("Trying to reconnect");
    Firebase.begin(FIREBASE_HOST, FIREBASE_AUTH);
  }

void loop() 
{
  if (Firebase.failed())
      {
      Serial.print("setting number failed:");
      Serial.println(Firebase.error());
      firebasereconnect();
      return;
      }
      
  val1=Firebase.getString("S1").toInt();                                        //Reading the value of the varialble Status from the firebase
  Serial.println(val1);
   Serial.println(val2);
    Serial.println(val3);
     Serial.println(val4);
  if(val1==1)                                                             // If, the Status is 1, turn on the Relay1
     {
      digitalWrite(Relay1,HIGH);
      Serial.println("light 1 ON");
    }
    else if(val1==0)                                                      // If, the Status is 0, turn Off the Relay1
    {                                      
      digitalWrite(Relay1,LOW);
      Serial.println("light 1 OFF");
    }

  val2=Firebase.getString("S2").toInt();                                        //Reading the value of the varialble Status from the firebase
  
  if(val2==1)                                                             // If, the Status is 1, turn on the Relay2
     {
      digitalWrite(Relay2,HIGH);
      Serial.println("light 2 ON");
    }
    else if(val2==0)                                                      // If, the Status is 0, turn Off the Relay2
    {                                      
      digitalWrite(Relay2,LOW);
      Serial.println("light 2 OFF");
    }

   val3=Firebase.getString("S3").toInt();                                        //Reading the value of the varialble Status from the firebase
  
  if(val3==1)                                                             // If, the Status is 1, turn on the Relay3
     {
      digitalWrite(Relay3,HIGH);
      Serial.println("light 3 ON");
    }
    else if(val3==0)                                                      // If, the Status is 0, turn Off the Relay3
    {                                      
      digitalWrite(Relay3,LOW);
      Serial.println("light 3 OFF");
    }

   val4=Firebase.getString("S4").toInt();                                        //Reading the value of the varialble Status from the firebase
  
  if(val4==1)                                                             // If, the Status is 1, turn on the Relay4
     {
      digitalWrite(Relay4,HIGH);
      Serial.println("light 4 ON");
    }
    else if(val4==0)                                                      // If, the Status is 0, turn Off the Relay4
    {                                      
      digitalWrite(Relay4,LOW);
      Serial.println("light 4 OFF");
    }    
}

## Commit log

2022-03-23 Update Firebase_HomeAutomation.ino
    prototype testing with Firebase
2022-03-23 Fritizing schematic file
    [MP3,Alarm.fzz]
2022-03-23 Fritzing schematic
    [MP3,Alarm.fzz]
2022-03-23 FlowChart file added
    FlowChart
